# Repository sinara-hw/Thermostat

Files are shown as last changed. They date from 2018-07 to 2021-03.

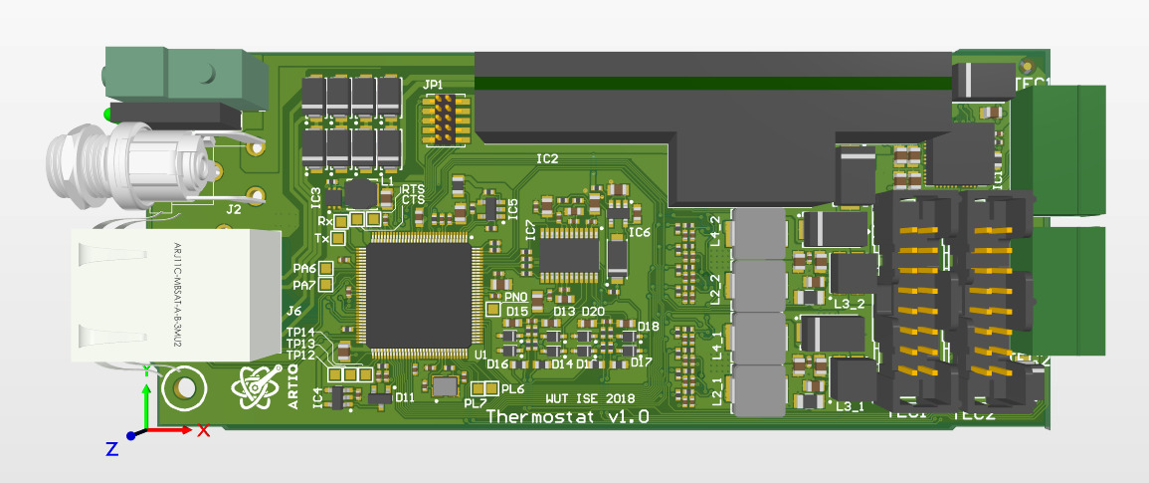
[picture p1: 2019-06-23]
DOC/Thermostat 3U_2.PNG

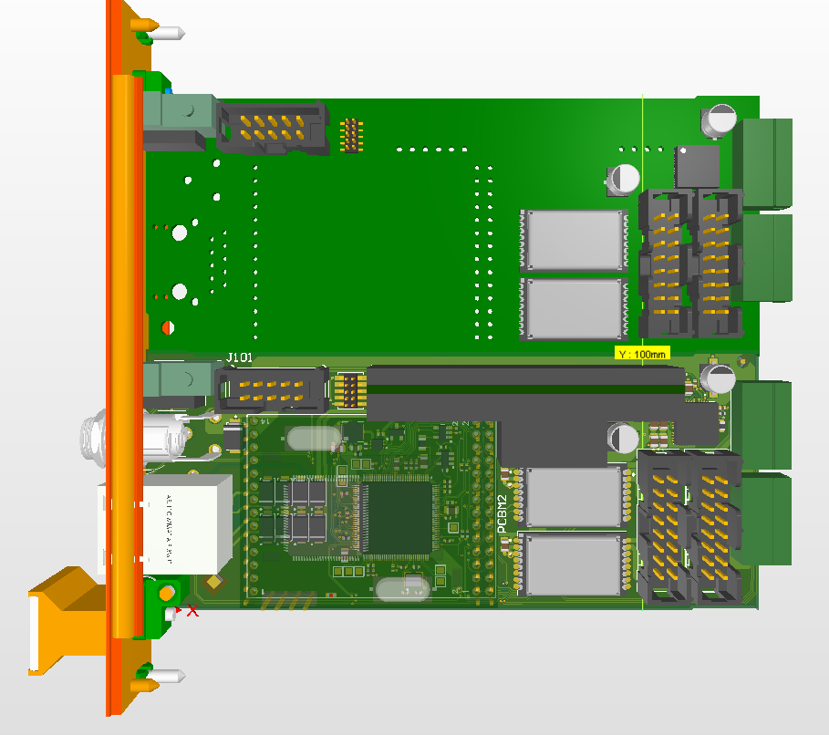
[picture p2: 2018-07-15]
DOC/Thermostat 3U_4.PNG

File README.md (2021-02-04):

# Thermostat

Thermostat is 2-channel temperature controller EEM based on the STM32 ARM processor, AD7172 and MAX1968  capable of driving 8W into a TEC or resistive heater.

## Design Files

Design files (schematics, PCB layouts, BOMs) can be found at [Thermostat/Releases](https://github.com/sinara-hw/Thermostat/releases).

## Wiki

More information can be found on the [wiki](https://github.com/sinara-hw/Thermostat/wiki).

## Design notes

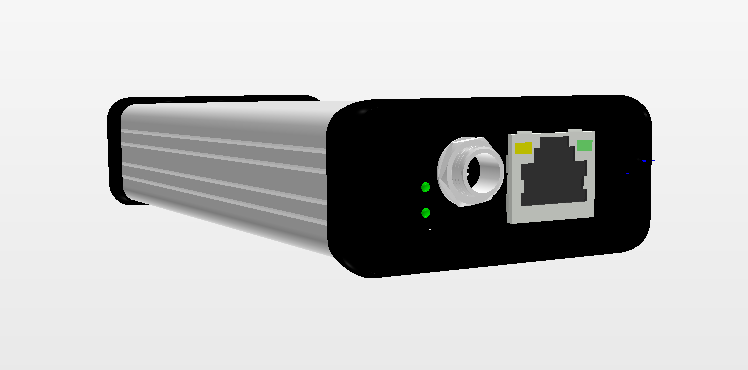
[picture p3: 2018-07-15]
DOC/Thermostat standalone_2.PNG

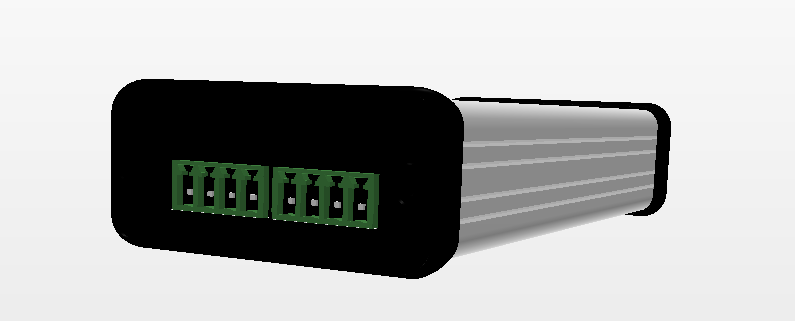
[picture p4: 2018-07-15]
DOC/Thermostat standalone_1.PNG

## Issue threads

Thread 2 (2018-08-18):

project review

gkasprow, 2018-08-18:
@hartytp @jordens I sketched first release.
Please have a look at it.
I also updated wiki with drawings.

jordens, 2018-08-20:
Nice!
1. I'd hook up the ENABLE pins to the uC plus pulldowns and alternatively 0R to GND.
2. You might want to check the output capacitor of the PoE module. They have 470µF there.
3. We need to check that we meet maintain power signature on PoE. That's a couple hundred mW mimimum power consumption IIRC. We should also avoid the acoustic noise the PoE module DS talks about when it runs at low power.
4. Isn't it more efficient to send 5V (instead of 12V) to the other board with the extension channels? The step-down module can handle it and the PoE module as well. You could even use one of those board-to-board edge connectors that you found for Sensor-Box.
5. Can we hook up the LED outputs of the wiznet module to the RJ45 jack LEDs as well?
6. Any chance we can connect pins 15 and 16 (I2C) of the Zotino-TEC connectors to the µC?
9. I'd explicitly pull up RESET of the wiznet module.
7. Congrats to squeezing it on two layers!

hartytp, 2018-08-20:
@gkasprow Great! Travelling atm but will probably be able to look at this in the next few days.

gkasprow, 2018-08-24:
4-channel extension lets you control second module equipped with just TEC controllers from first module with Ethernet, PoE and DC/DC. I'm a bit afraid of exposing 5V to the panel. Someone may plug 12V supply by chance since other EEMs offer such ability.

hartytp, 2018-08-24:
> 4-channel extension lets you control second module equipped with just TEC controllers from first module with Ethernet, PoE and DC/DC.

Okay, makes sense. Have you designed this board yet? Is it worth doing this? IMHO, if people need 4 channels, it's easier to just have two identical thermostat cards with separate ethernet/PoE connections, instead of having to have two separate (non-identical) boards. So, I'd be tempted to scrap this, I don't feel strongly about it.

Also, is there enough power from the PoE module to run 4 TECs safely?

> I'm a bit afraid of exposing 5V to the panel. Someone may plug 12V supply by chance since other EEMs offer such ability.

I meant removing the barrel connector completely and only supporting PoE (I thought this is what we had agreed before). PoE injectors are pretty cheap, so I don't see much need to support both PoE and barrel connectors.

gkasprow, 2018-08-24:
@hartytp It is the same board, but without PoE and Ethernet module.
PoE is rated for 35W

hartytp, 2018-08-24:
sounds good then.

One final request: could you add a comment on the schematic with the p/n (and mating p/n) for those din connectors, please? That way I don't have to load the alltium files to figure it out.

hartytp, 2018-10-09:
Good find. If you use them, let me know how they work out.

gkasprow, 2018-10-09:
@jordens I use them in the lab. I already posted [pics ](https://github.com/sinara-hw/sinara/issues/188#issuecomment-327180612) with them some time ago :) They are really nice.

hartytp, 2018-10-09:
@gkasprow did you ever produce any Thermostat prototypes? I'd like some if they're going :)

gkasprow, 2018-10-09:
Not yet, I'm collecting designs to spare on NRE costs. I will produce it together with Banker extension boards.

hartytp, 2018-10-09:
Good plan. I'm not in a massive hurry for this, but it would be nice to have at some point.

hartytp, 2018-10-09:
Closing this issue since I think the design review is not complete

Closed 2018-10-09.

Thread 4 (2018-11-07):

thermostat v2.0

hartytp, 2018-11-07:
We've had some problems recently with a common commercially available temperature controller, which we've tracked down to inadequate EMI filtering in the temperature controller AFE and use of unscreened cabling in the wiring harness provided by a different vendor (the 10k NTC has a 100uA sense current so is a high-impedance node which is very prone to pickup even at 50Hz).

To solve this, I'd like to swap out these temperature control units for Thermostat, but there are two annoyances:
1. The specified temp co of the Thorlabs chip is quite high and likely to be problematic if we don't temperature stabilise Thermostat, which is a pain
2. We use a resistive heater rather than a TEC for this project. AFAICT there is no software option to make the Thorlabs chips run unipolar (AFAICT the designers didn't consider resistive heaters as an option so didn't bother to implement this in firmware). So, if any transient reduces the heater current below 0 then it will go into thermal run away.

So, I'd like to revive the discussion about replacing the Thorlabs chip with something along the lines of @cjbe's design based on a 24-bit ADC and the Maxim TEC driver IC. As a reminder, the big win from using a 24-bit sigma-delta ADC is that the sample rate is high and the ADC includes very good digital filtering (including extreme rejection of 50/60Hz signals). Combined with a basic CM/DM analog RFI filter, this provides a level of EMI rejection that is essentially impossible to achieve in the analog designs that seem to be used in almost all COTS units. Using @cjbe's prototypes of this design, we were able to achieve stabilities better than 100uK long term without issue.

As I see it, the main challenge here is software. The hardware redesign is very easy and I'd be happy to do that myself using @gkasprow's Altium library. The more involved part is writing decent software: command handler; simple PI(D?) loop; some basic features like thermal runaway detection, current limiting, anti-wind up, etc. I don't have time to do that part. @gkasprow do you have a student who might be interested in doing that? (otherwise, if anyone is potentially interested in funding M-Labs to do this then let us know!)

gkasprow, 2018-11-07:
@hartytp I can add AD7191 to existing design. @cjbe how did you couple the PIC processor with  MAX1968 CTLI input? Using PWM?

gkasprow, 2018-11-07:
We can ask the student to port the PIC code to the TI CPU.

hartytp, 2018-11-07:
> We can ask the student to port the PIC code to the TI CPU.

Which PIC code do you mean?

gkasprow, 2018-11-07:
https://github.com/sinara-hw/Thermostat/issues/5#issuecomment-357445261

cjbe, 2018-11-07:
@gkasprow yes - I generate the CTLI signal from a PWM output and a two-pole reconstruction filter (10k,100n).

hartytp, 2018-11-07:
@gkasprow perfect! I agree: these should be two separate designs rather than trying to fit everything on one board. The Thorlabs version gives us something we can use with minimal effort/risk of hardware bugs, the ADC version should work better in the long run but will need software development and careful hardware characterisation.

gkasprow, 2018-11-07:
@hartytp please have a look
[Thermostat.PDF](https://github.com/sinara-hw/Thermostat/files/2559336/Thermostat.PDF)

hartytp, 2018-11-08:
@gkasprow wow! Thanks for turning that around so fast!

@cjbe any thoughts? Things you'd want to change if you did this design again?

Basically that looks good to go as far as I'm concerned. Small thoughts/comments:
- Cosmetics could be improved but that's non-crucial e.g. would be nice to neaten things up a little, add a power budget, etc. (e.g. I find the fact that the signal flow is R->L on the 3v3->vcc->vref block on the adc makes things a bit hard to follow)
- @cjbe's design is a bit long in the tooth now and there are newer better ADCs around. However, based on his design notes, it seems that the ADC isn't really a limitation here. The only way I can see where the ADC comes close to being a limitation is the +-1ppm/K gain drift. The best ADCs on the market are still only a factor of two better than that, so the overall improvement is relatively small. Probably not worth the hassle of switching ADCs.
- what are the inductors on the TEC driver? Let's use ones that retain their inductance at 1.5A and pick ones that won't radiate like crazy!

jordens, 2018-11-08:
As a humorous side remark: I've heard talks by high profile representatives of well known companies in all seriousness claiming that inductors are what's limiting miniaturization, integration, scaling, and technological progress in laser current and TEC drivers.

hartytp, 2018-11-08:
@gkasprow what capacitors (voltage rating, case size, dielectric) are you using for IC1? That reg needs 1uF for stability, so we need to make sure we don't use a cheapo ceramic which gives far less capacitance when biassed.

gkasprow, 2018-11-08:
You won't find 1uF NPO. I used X7R.

hartytp, 2018-11-08:
Yes, X7R is good for this, but we need to watch the case size and voltage rating or the capacitance can be way lower than expected. Since this is required for stability, I'd probably make it a slightly higher capacitance and use a decent voltage rating and case size.

hartytp, 2018-11-08:
Can you add an annotation that the 5k11 resistors must be 5ppm/K temp co?

(if you upload the altium files I'm happy to do this).

hartytp, 2018-11-08:
@gkasprow let's tie the ADC CLKSEL high to ensure the internal clock is correctly enabled.

hartytp, 2018-11-08:
let's connect the ADC TEMP pin to the microprocessor to allow access to the ADC's on-board temperature sensor.

hartytp, 2018-11-08:
ADC NC should be tied to GND according to the data sheet.

hartytp, 2018-11-08:
We're driving the ADC AVDD and DVDD from the same supply. Usually, I would expect to provide separate supplies for these (e.g. connect the DVDD to P3V3A via an independent 33R resistor with a 1uF||100nF capacitor). @cjbe I guess the reason you chose not to do that in your design is that we keep the digital interface inactive during sampling so we don't need to worry about noise on DVDD. Is that correct, or is it worth isolating?

hartytp, 2018-11-08:
> I used tiny SMD shielded inductors that saturate at 3A.

Since the MAX1968 max output current is +-3A isn't it worth using inductors that saturate at something a bit higher than 3A. We don't want to operate the converter with the inductors close to saturation do we?

hartytp, 2018-11-08:
@gkasprow it's definitely worth adding some schottky diodes to protect the ADC inputs in case the user messes up the wiring harness and connects the TEC outputs to the thermistor input. That would put 5V across the ADC inputs, resulting in an ADC input current beyond the 10mA abs maximum rating. Just use the same diodes on Sampler (to be extra sure, we can split the 100R into 50R->diodes->50R->ADC).

hartytp, 2018-11-08:
not that it really matters, but afaict it's more natural to connect LX2 to tec_n and LX1 to tec_p (i.e. swap the _p and _n around on the tec connectors).

hartytp, 2018-11-08:
Is it worth having a CMC on the TEC outputs to reduce EMI (there is quite a lot of common-mode noise on those outputs)?

hartytp, 2018-11-08:
The TEC driver recommends having a 100uF electrolytic somewhere on the supply to smooth out ripples. Worth adding one?

hartytp, 2018-11-08:
> The TEC driver recommends having a 100uF electrolytic somewhere on the supply to smooth out ripples. Worth adding one?

NB on @cjbe's design this wasn't necessary since we had an external 5V supply with a big output capacitor. However on Thermostat the 5V is sourced from an internal 5V SMPS.

gkasprow, 2018-11-08:
We have to relay on 5V supply itnernal protection then.

hartytp, 2018-11-08:
> We have to relay on 5V supply itnernal protection then.

That can supply 8A, which is more than enough to trash one of the max chips.

I don't think there is any way of getting around this; mis-wiring the connector so that TEC_N, but not TEC_P, is shorted to V+ or GND will always kill this chip.

hartytp, 2018-11-08:
@gkasprow anyway, I don't think this needs to turn into a multi-round review. Do what you think is best based on my feedback, and let me know when you're happy with the design. Once that's done I'll order a few boards from TS to play with.
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
hartytp, 2018-11-13:
> Performance is probably going to be fine for most applications. And if it hinges on me finding a better bridge chip doing the design, then I'll pass ;) And this is probably fine as a first iteration.

Well, it hinges on someone doing the design. I'm short on time right now and the MAX IC will be absolutely fine for all the applications I have in mind, so it won't be me who does all the legwork for this. If you can convince someone else to do the design work required for this then it's fine by me.

What do you think @gkasprow

> In any case, don't you want to wait and debug the parts of the design shared with the Thorlabs version first before signing this one off?

By this point, there isn't much common between the two boards, and I have some temperature control needs coming up for which the Thorlabs chip is a bit marginal. So, unless someone is planning to test the Thorlabs version of Thermostat reasonably soon then I'd prefer to press on to manufacture.

gkasprow, 2018-11-13:
@jordens The MAX works at 1MHz. Even with 10 bit PWM you would need 1GHz clock in CPU. One can do some tricks with 8 bit PWM and noise shaping but IMHO it is not worth the effort.

jordens, 2018-11-13:
The PWM from the CPU to the MAX will also need dithering to get the needed resolution. There is no change from that.

jordens, 2018-11-13:
Even if you were to stay at plain PWM from the CPU, you get even more resolution by adjusting the frequency. The continued fraction algorithm to do that will fit just fine into the ~10ms sample rate. I assume that's what @cjbe was already doing.

hartytp, 2018-11-13:
> Even if you were to stay at plain PWM from the CPU, you get even more resolution by adjusting the frequency. The continued fraction algorithm to do that will fit just fine into the ~10ms sample rate. I assume that's what @cjbe was already doing.

@cjbe

gkasprow, 2018-11-13:
I"d like to treat the version with MAX chip as a first iteration.
 Doing own HW bridge with cycle per cycle current sensing needs quite sophisticated mechanisms inside of the CPU.
Once I did laboratory grade BLDC motor driver using brand new special AVR chip dedicated for that tasks with special high resolution PWMs with HW dithering, synchronous ADCs, HW protections, etc but it took  enormous amount of time due to bugs in the silicon. Finally I had to build required functions writing critical parts in assembly. And I burned a lot of MOSFETs during testing because HW protection functions (programmed using fuses) did not work as expected causing spectacular failures by switching top and bottom switch at the time :)
Every design can be made better, but if MAX chip does the job and simplifies R&D, let's use it. If we discover that it does not meet our expectations, we will switch to something else.

hartytp, 2018-11-14:
@gkasprow It sounds like the plan is to keep the MAX IC for Thermostat v2.0. If we decide it's not good enough, we can replace it in v3.0. Thermostat v2.0 will give us a high-performance board that we can develop most of the required firmware on.

Please could you update following @jordens comments (copied below) and then upload a release and close this issue?

- [ ] also connect I2C on the second TEC to the CPU. I2C2 or I2C3 (when moving STAT) seem doable on quick glance.
- [ ] Please expose the UART not on individual pads but on a pin header.

gkasprow, 2018-11-17:
done for both designs.

hartytp, 2018-11-17:
Thanks!

Okay, let's close this. We'll keep the new TEC driver design in mind for v3.0

Closed 2018-11-17.

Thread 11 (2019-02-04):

replace PWM with a DAC

hartytp, 2019-02-04:
I'd like to replace the PWM for the TEC controller with 16-bit I2C DACs with internal references like AD5693R to the next revision. Seems easier than fighting to squeeze the last bits out of PWM and won't make a significant impact on the board ownership. We can always re-visit PWM if we move to a custom TEC driver in a future revision.

Any objections?

gkasprow, 2019-02-04:
@hartytp sorry, I have higher priorities. I'm just moving all Sayma/Metlino designs to AD19. Mentor didn't agree to renew the Xpedition license for WUT. Once Siemens bought Mentor, the rules changed.
We still have a commercial license but it expires in March. After that, we won't have any. I got to know about it a few days ago... I will write another post about it.

hartytp, 2019-02-04:
Ack no problem. Can you post me the boards then and I’ll make the changes.

First, any objection to adding DACs (@jordens).

hartytp, 2019-02-15:
@gkasprow to ensure that Thermostat works well for high dynamic range applications, let's go for an 18-bit DAC.

AD5680 looks to be a good choice. NB INL is really quite large (12-bit accurate, but 18-bit montonic), but that's not an issue for this kind of application. It does require an external reference. The reference doesn't need to have a low temp co or amazing low frequency noise since it's mainly intended to be used closed loop. So, pick any suitable buffered ref. A common reference for the two DACs will be fine.

hartytp, 2019-02-16:
Thinking about this a bit more, it's probably best to use the TEC driver's REF output for the DAC reference.
- the TEC has a low-accuracy, somewhat drifty reference. This sets the control voltage that gives 0 TEC current. For systems that use low TEC/heater currents, getting this right is quite important.
- our original plan was to use an ADC to calibrate the TEC driver reference using the reference output pin. This relies on having quite accurate ADCs in the microprocessor and uses a bit more software work.
- let's just use a cheap low-speed OpAmp in a small package like 5-pin SOT as a 2x buffer to cover the TEC reference to a DAC reference. That way most systematics common-mode out and we don't need to bother with software calibration or external references.
- If we do that, it makes sense to use a DAC with decent offsets/INL, so I'll pick a different PN

jordens, 2019-02-16:
Are you sure the zero offset is critical? It only determines the proper reset value of the integrator and it is only as critical as accurate knowledge of the ambient temperature.

hartytp, 2019-02-21:
> It only determines the proper reset value of the integrator and it is only as critical as accurate knowledge of the ambient temperature.

For TEC/heater currents that are larger than the offset, that's true. However, if the TEC/heater current gets smaller than the offset then the sign of the feedback gain changes, which can get a bit nasty (Thermostat thinks it's heating when it's actually cooling).

Anyway, this isn't an issue for any of the systems I have in mind, so I haven't put much thought into it.

> Thinking about this a bit more, it's probably best to use the TEC driver's REF output for the DAC reference.

Actually, I'm not sure this is worth the effort. To get decent accuracy, we'd need a resistor ladder/PGA and it's not at all clear that the gain would be worth it.

Once we have a PN for the microprocessor, we should check the accuracy of the ADCs and decide whether it's worth doing a power-on calibration of the TEC driver reference + DAC offset or not. This is a pretty low priority for me though.

gkasprow, 2019-02-21:
we can assume same CPU PN as in the Stabilizer.

hartytp, 2019-02-21:
Okay, those ADCs look pretty good. I suspect that if we measure the DAC offset with the same ADC as the TEC driver offset, the ADC offsets will common-mode out, so we should get a nice accurate measurement of the zero-point current without any clever tricks.

We could derive the DAC reference from the TEC controller to take out drifts/noise in the TEC controller reference after calibration, but I don't think it's worth the effort.

jordens, 2019-02-21:
> For TEC/heater currents that are larger than the offset, that's true. However, if the TEC/heater current gets smaller than the offset then the sign of the feedback gain changes, which can get a bit nasty (Thermostat thinks it's heating when it's actually cooling).

I don't think so. This sounds like the typical wrong PID design (gain after integration instead of the other way around).

hartytp, 2019-02-21:
Yes, you're right, it's not an issue. Anyway, it's not relevant for the use cases I have in mind, so wasn't putting enough thought into it. Glad you're paying more attention!

gkasprow, 2019-06-21:
The CPU has 2 DAC output channels. Can we use them for something instead of PWM?

gkasprow, 2019-06-21:
@hartytp What is the conclusion for driving the DAC reference? We will measure the TEC ref with CPU ADC?
I already connected it in such manned.

hartytp, 2019-06-21:
Yes, let’s connect the tec driver ref to an ADC. Drive the dac ref from a buffered voltage reference.

Closed 2019-06-23.

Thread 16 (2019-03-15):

enclosure mechanics

jordens, 2019-03-15:
* The tantalum cap in the corners next to the green terminals and the IDC connectors are too close to the enclosure
* There are PCB traces at the edge that risk being scratched and shorted by the enclosure when inserting
* The pins from the RJ45 and the green terminals touch the enclosure.
* Inserting it in the second slot from the bottom doesn't work because of the RJ45 connector.

I'd make sure that there is enough clearance to the side slots (tantalum, IDC, other parts parts and traces) and that the pins are cut.

gkasprow, 2019-06-23:
we are switching to 4 layer PCB anyway so this will solve some of the issues.
THT pins need trimming before placing in the enclosure.

hartytp, 2019-07-15:
I also had issues with the PoE module colliding with the side on one board. Maybe it was soldered on at a bit on an angle, but I had to bend it in to prevent some thicker components from colliding with the enclosure.

gkasprow, 2019-10-26:
All issues fixed. At least on the 3D model.

Closed 2019-10-26.

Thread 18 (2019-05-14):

add GPIO header?

sbourdeauducq, 2019-05-14:
What about adding a GPIO header connected to the otherwise unused pins of the STM32?

The immediate application I have for it is connecting a current source driving a laser diode, to study its behavior under different temperature and current conditions. With that GPIO header, the diode driver could be a simple stripboard add-on.

gkasprow, 2019-05-14:
What about using same connector as for Stabilizer , routed to same CPU
pins, so one can reuse same mezzanines?

hartytp, 2019-05-14:
The Stabilizer connector is probably too big for Thermostat. I'd prefer not to increase the board area too much for a niche feature.

jordens, 2019-05-14:
I would prototype a current driver on Stabilizer or any of the other µC (e.g. Nucleo) boards and use Thermostat separately.
If there is space for a connector without disturbing the layout, introducing clearance problems, or changing the board size I'm ok with adding one.

sbourdeauducq, 2019-05-14:
> I'd prefer not to increase the board area too much for a niche feature.

Niche?
I thought one of the main applications of the thermostat was to stabilize the temperature of laser diodes, and those almost always needed programmable current sources.

gkasprow, 2019-06-23:
what signals would you want on such header?
I have some board are and can place 10 pin 2.54mm header.

gkasprow, 2019-06-23:
I can route 2 ADC, 2 DAC and some GPIO

sbourdeauducq, 2019-06-23:
Okay, sounds good!

Closed 2019-06-23.

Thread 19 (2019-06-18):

AD590 temperature sensor support?

sbourdeauducq, 2019-06-18:
The AD590 seems to be a popular option in several commercial or academic ECDL designs, and it might be interesting to support it.

gkasprow, 2019-06-19:
it is current output sensor, with 1uA/K conversion ratio.  It gives 300uA at room temperature and 220uA at -55degC.  The only issue is the power supply. It needs a minimum of 4V. We would need to hook it to 5V rail and measure the voltage on a resistor connected to GND. If we use existing 5k11 resistor, we would get
1.55 V at room temperature so 5V supply would be not enough. So the resistor must be lowered to roughly 3k to maintain the best SNR. The negative terminal of the ADC would need to be shorted to GND.
So, there is a way to do it but it would require additional LDO that stabilizes 5V to let's say 4.8V, some jumper that chooses the lower value of the resistor and yet another one that connects LDO output to positive ADC pin.

hartytp, 2019-06-19:
The current thermostat design is optimized for ratiometric measurements of resistances ~10k. In particular, this allows us to avoid using a high-spec reference, since the reference voltage/noise common-modes out.

The AD590 is quite different since we'd need to measure an absolute current/voltage across a sense resistor. 1mK/300K=3ppm. So the noise/drift on the reference has to be very low to achieve decent stability. Moreover, to get 0.5C accuracy on 300C you need the reference to be good to 0.1%, which the current implementation isn't.

So to make this work we'd need to overhaul the ADC supply/reference.

hartytp, 2019-06-19:
Assuming we used a 1V sense resistor, the 1mK=1nA*1kOhm=1uV. So, we'd need to be very careful to make a proper differential/kelvin-connection measurement across the sense resistor. The current circuit topology doesn't allow that. I suspect that just grounding one ADC input and making a single-ended measurement of the sense resistor voltage won't give very good results.

hartytp, 2019-06-19:
In other words, this is something we can do with a handful of jumpers (maybe FETs, but that would need some thought) and an overhaul of the ADC reference/supply, but it's not a trivial change.

I wouldn't support going down this rout unless someone wants to take ownership of it and provide a sketch of what conenctions we'd need, along with a noise/stability analysis and a specification of what they're trying to achieve. If no one has time to do that right now then let's leave it to a future design revision (or maybe a design variant).

jordens, 2019-06-19:
Thermistors are also about 20 times more sensitive than a PTAT. That translates to controller performance accordingly.

gkasprow, 2019-06-23:
nothing to do here, closing.
I don't have space on PCB to add jumpers.

hartytp, 2019-06-24:
I think the best thing is to make a separate PCB for the AD590 if people need that. The front-end circuit required for the AD590 is sufficiently different to RTDs to make supporting both tricky without significant space/complexity increases.

Closed 2019-06-23.

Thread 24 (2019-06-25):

ic1 sw pins connection missing

hartytp, 2019-06-25:
why aren't pins 10 and 48 tied together?

hartytp, 2019-06-25:
@gkasprow answering my own question, I guess the reason is that there are two banks of SW pins on opposite sides of the IC and you don't want to route them together.

Also, I haven't checked the compensation for this reg, but assume you're happy with it?

gkasprow, 2019-06-26:
I took the values from the datasheet.

hartytp, 2019-06-26:
@gkasprow looking at the example layout (fig 6-1) the two sets of switch pins should be tied together with a thick trace.

hartytp, 2019-06-26:
@gkasprow I didn't see much guidance in the data sheet on the choice of Cinj and Cff. It looks a bit like they have to be chosen empirically (depends a lot on the ESR of the capacitors used). Are you happy with the values there? Did you check the stability/noise of this regulator?

gkasprow, 2019-08-18:
I took them from the [reference design](https://www.arrow.com/en/reference-designs/mic45116-1ymp-ev-evaluation-board-for-the-mic45116-1-20v6a-dc-to-dc-power-module/98683d59703926eaa41bfb0839684ba1)

gkasprow, 2019-10-26:
I think I have to look at it once again and verify its stability with a step response test.
The sudden death of the 3V3 converter made me suspicious. I'm using this configuration in a few other designs and nobody complained so far but since a lot depends on load, who knows...

gkasprow, 2019-10-26:
I can also do it with V2.0 since I don't have any thermostat in my hands.

hartytp, 2019-10-27:
Happy to send you one if it would help?

gkasprow, 2019-10-27:
I have other design with an identical converter so can use it for testing.
I do a very simple test:
 Connect a scope and a pushbutton with a 2R/5W resistor in series.
One probe goes to the switch, another to the power rail. Then trigger on falling and rising edge and observe the response. It cannot oscillate. If it does, there are stability issues.

hartytp, 2019-10-27:
Good idea. FWIW I think we’re running at a quite light load, not sure how that impacts stability

hartytp, 2019-11-30:
@gkasprow are you happy the layout for this ic follows the reference design?

gkasprow, 2019-11-30:
yes.

Closed 2019-11-30.

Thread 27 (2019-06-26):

DAC reference

hartytp, 2019-06-26:
@gkasprow shouldn't we use a 3V reference for the DAC to match it to the TEC driver? Currently we're throwing away nearly an entire bit of resolution by using the wrong reference.

gkasprow, 2019-06-26:
True. We can also add resistive divider but the reference is probably cheaper.

hartytp, 2019-06-26:
Nb the dac still needs a decent 5V rail as it doesn’t support 3V vcv

hartytp, 2019-06-26:
> True. We can also add resistive divider but the reference is probably cheaper.

Actually, we can probably get away with a divider made from 0.1% resistors. After all, the DAC offset is 10mV, which is 0.3%, so a small error on the reference won't harm us.

hartytp, 2019-06-26:
And, DAC gain accuracy is only 1.5% so no point having an ultra-precise reference.

The main worry I'd have would be the higher reference impedance degrading the DNL. @gkasprow am I right in thinking that for this kind of resistor string DAC, that shouldn't be a problem since the ref current is constant? Or do we need a proper buffered reference here?

gkasprow, 2019-07-12:
@hartytp AD5680 has already buffered output. So we can add resistors.

hartytp, 2019-07-12:
Won’t it be an issue that the ref impedance at the ac will be high due to the resistors? Doesn’t the dac need a low impedance red?

gkasprow, 2019-07-13:
Oh, I was thinking about adding voltage divider at the DAC output to match the range.

gkasprow, 2019-07-13:
we can also use the ADC 3.3V supply as a reference.

hartytp, 2019-07-13:
Aah ok. So long as the tec and cpu ADC inputs are high z, a divider on the dac output sounds like the best option

gkasprow, 2019-07-13:
MAX1968 has 1MOhm input resistance. We don't really care about DC accuracy. So resistive divider in order of 1k should be fine.

hartytp, 2019-07-13:
Sounds good

Closed 2019-08-18.

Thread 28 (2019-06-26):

mesaure DAC output on microprocessor

hartytp, 2019-06-26:
@sbourdeauducq should we wire the DAC output to a microprocessor ADC input? The DAC only has 12-bit accuracy (10mV offset), which is comparable to the TEC driver. No point calibrating the TEC if we don't calibrate the DAC as well.

hartytp, 2019-06-26:
This also means we're not sensitive to offsets in the microprocessor ADC since they common-mode out on the two measurements (we're effectively finding the DAC word that makes the DAC output equal to the TEC ref value).

gkasprow, 2019-06-26:
>  The DAC only has 12-bit accuracy (10mV offset)

Do you mean the CPU ADC?

hartytp, 2019-06-26:
No the 18 bit DAC is only 12 bit precise as it’s designed for in loop applications like this. 18 bit accurate dacs cost $$$ this one is cheap. Stability and noise are good so it’s fine for our application

hartytp, 2019-06-26:
CPU ADC offsets don’t matter so long as we measure the dac outputs and tec ref on the same ADC

gkasprow, 2019-06-26:
I added another RC to isolate the DAC from the CPU ADC sampling current pulses

hartytp, 2019-06-26:
When did you add that?

gkasprow, 2019-06-26:
a few seconds ago.
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

hartytp, 2019-06-26:
Did it make any difference?

hartytp, 2019-06-26:
In the first instance, let's try to focus on allowing you to reproduce my results on an unmodified board. See if you can get +10V on channel 0 and -10V on channel 1 by flashing according to Robert's instructions. If not, I'll have another look at the FW I sent you in the morning.

gkasprow, 2019-06-26:
It's thermostat issue, not stabilizer :D

hartytp, 2019-06-26:
:) sorry. Doing too many things at once

hartytp, 2019-06-26:
Looks good

jordens, 2019-06-30:
When using the DAC and PWM Vref calibration values that you would obtain from this, I'd be very careful what to do with them. Initial one-time offset calibration, monitoring and correcting the limit PWMs later on are fine. But I don't think repeated feedback of those values onto the Iset DAC output are a good idea.

hartytp, 2019-06-30:
@jordens yes I’d go for a power on cal and leave it there.

Closed 2019-08-18.

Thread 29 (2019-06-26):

schematic review

hartytp, 2019-06-26:
I've checked the supplies and analog parts and am happy. @sbourdeauducq / @jordens would you mind checking that you're happy with the digital side of things?

gkasprow, 2019-06-26:
I posted also CubeMX config files, so one can with one click generate all init software for specified pin assignment and peripherals.

jordens, 2019-06-30:
I would recommend testing and characterizing the analog parts sufficiently before doing the redesign.

hartytp, 2019-06-30:
@gkasprow do you have a thermostat set up with firmware already? Do you think you could have a quick look at the temperature stability this week? Just connect a low temp-co 10k resistor in place of a RTD and log the temperature for a few hours.

gkasprow, 2019-06-30:
I don't have any Thermostat at the moment.

hartytp, 2019-06-30:
I have a spare one I’m happy to send you (btw did TS send you a stabilizer current sense AFE?)

gkasprow, 2019-06-30:
I gave one to Creotech, can take it back if they don't use it. I didn't get stabilizer AFE from TS. Note that at the end of next week I'm leaving for the holidays. I will stay for one month in the US.

hartytp, 2019-06-30:
> I gave one to Creotech, can take it back if they don't use it.

Okay, I'm happy to overnight you one tomorrow if it would help.

> Note that at the end of next week I'm leaving for the holidays. I will stay for one month in the US.

I think it's important that we try to get the boards off before you leave. I need to get hw produced before too long so that M-Labs can write the new firmware. Let's do as much testing as we can (I will try to do some as well), but still aim to get production files ready by the end of the week. (@jordens / @sbourdeauducq can you try to finish your design reviews in the next few days?)

> I didn't get stabilizer AFE from TS.

Odd, I asked them to send you one. They must have forgotten. I can ship at the same time as Thermostat or bring one to NACTI if that helps?

gkasprow, 2019-06-30:
You can bring to NACTI.

hartytp, 2019-06-30:
Okay. I’ll do what testing I can this week (anything anyone else can do gratefully received) but let’s aim to get the next design rev ready for production before @gkasprows holiday

hartytp, 2019-07-03:
@jordens @sbourdeauducq other than the thermal management have you completed your design review?

jordens, 2019-07-03:
I have reviewed everything in my area of expertise except the µC pin assignment. With the pending changes, that'll change quite a bit. Someone should take a good long look at that the choice of peripherals, timer channels, w.r.t. pins, internal buses, dma architecture, peripheral capabilities etc. I won't have much time to do that in the next weeks.
And I would still recommend that someone does a decent amount of characterization and testing of the current device. Both ADC and TEC driver.

gkasprow, 2019-07-03:
For this purpose, I use STM32CubeMX which does most of the job you mentioned.

jordens, 2019-07-03:
Sure. Some. It didn't cover the peripheral specific properties for stabilizer for example.

Closed 2019-10-26.

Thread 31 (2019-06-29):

AG5300 bypass/EMI filters (was: ripple capacitor)

jordens, 2019-06-29:
Should be 470 uF, is 460.
Imo going to 3*220 would be nice.

Also and maybe more importantly:
Is there some way to mitigate the ground ripple?
Since it's an actual isolated transformer I would not have expected ground loops that bad.

gkasprow, 2019-06-29:
it does not make any difference because tolerance of electrolytic caps is usually 20% or worse.
A higher value may cause PSE tripping.

jordens, 2019-06-30:
What about adding the bypass caps (4.7nF 2000V) around the module and the choke for emi filtering as in the datasheet (fig13)?

gkasprow, 2019-06-30:
Good idea. The same with Stabilizer.

jordens, 2019-06-30:
Although the RJ45 connector seems to contain some caps already.

gkasprow, 2019-06-30:
Yes, but they are in series with 75Ohm.
The CMC and cap mentioned in the datasheet are used to make a bypass for PoE module Flyback converter.
The converter injects noise between primary and secondary side. Cap placed between them shorts the interferences and CMC is used to break the ground loop.

jordens, 2019-06-30:
But interestingly there are no caps on the non-data pairs.

gkasprow, 2019-06-30:
The RC network inside of the RJ connector serves a different purpose. It is so called "Bob Smith" termination. However, there are [doubts](https://www.eetimes.com/document.asp?doc_id=1277940#) if the values are correct.

gkasprow, 2019-06-30:
The conclusion is that we would need CMC to keep Bob Smith termination working. This affects EMI performance.

hartytp, 2019-06-30:
> Since it's an actual isolated transformer I would not have expected ground loops that bad.

To be clear, are you referring to https://github.com/sinara-hw/Stabilizer/issues/17#issuecomment-506049460

hartytp, 2019-06-30:
> The CMC and cap mentioned in the datasheet are used to make a bypass for PoE module Flyback converter.

@gkasprow which CMC? I only see ferrets there

hartytp, 2019-06-30:
@gkasprow can you sketch out your recommended circuit for this?

hartytp, 2019-06-30:
When I was looking at noise on Stabilizer, I didn't see a difference between powering from PoE or an external power supply. However, I did notice that when I turned the the PoE switch on with no cables connected (other than the power supply) I suddenly saw a lot of switching spikes on my scope. Maybe it's an issue with the particular switch I'm using, but maybe we should be prepared for some grounding/noise issues with PoE...

jordens, 2019-06-30:
Yes. It looks very different depending on the switch, the PoE mode.

gkasprow, 2019-07-12:
added CMS and caps.

hartytp, 2019-07-12:
Nice. Can I see the circuit you added? Did you use cmcs or inductors (as in the data sheet?)

gkasprow, 2019-07-12:
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

hartytp, 2019-07-12:
Wouldn’t inductors/fbs be better? We want to block both the cm and the dm signal, but the choke only gets the cm.

hartytp, 2019-07-12:
Also do c3 and c12 need to be he caps? And should we use 4.7nF input to output caps instead as in the data sheet?

gkasprow, 2019-07-13:
True, we can add inductors, but CMCs are much smaller. The main issue is common-mode noise caused by the DC/DC converter. The inductors in the datasheet of the PoE module are ferrite beads that have Z close to zero for SMPS frequency. C3 and C12 need to be high voltage caps to be compatible with Ethernet isolation barrier. Their role is to make a bypass for PoE noise source.

hartytp, 2019-07-13:
Okay so long as you’re not worried about dm noise currents radiating and causing emi issues that sounds good.

Closed 2019-07-12.

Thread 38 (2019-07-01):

evaluate thermal design and cooling requirements

jordens, 2019-07-01:
From a rough calculation where the three switchers (PoE, the 12V-5V, and the MAX) are each about/at most 90% efficient, we'll be loosing more than 30% in the device (plus µC, MAC, ADC, DACs, LDO, references). At `3A*4.3V*2` that's 26W to the Peltiers and we will be burning another 9W on top on this tiny board. That number is typically reached each time during turn on for a significant duration. (I have seen it use about 17W from PoE+ when driving a single channel. That wasn't even max power.)
This means:

* In unconstrained applications we'll max out the PoE allowance (25.5W available at PD since you need to account for cable losses). This will require careful and active management in software. It's not a killer. But it means that it will be impossible to get full power out of both peltiers at the same time for a significant duration. If it's not managed in software this will be annoying and confusing at the very least.
* Since there is no way for the software to distinguish PoE (where AT_DET is deasserted) from external 12V (where it is deasserted as well) using the 12V external will mean running at 13W max from the barrel connector. If this is undesired we need a way to distinguish the power sources.
* For PoE power at full output we'd burn more than 8W on the device. For external 12 V at full beans it's more than 5.5W. This will likely overheat if continuous. One way to tackle this may be to try to get some conductive cooling working to the Hammond enclosure: add tight coupling between the PCB layers, add exposed copper/gold strips on the outside where the PCB slots into the enclosure and design two wedges that are inserted from rear and front on top of the PCB between the enclosure and the exposed strip to make thermal contact. Admittedly that's a hack and tricky. If that doesn't work, we need to look at something else. E.g. actively limit the Peltier voltage depending on internal (ADC, µC) temperatures.

hartytp, 2019-07-01:
@jordens all good points. Thanks for the detailed work on this.

> Since there is no way for the software to distinguish PoE (where AT_DET is deasserted) from external 12V (where it is deasserted as well) using the 12V external will mean running at 13W max from the barrel connector

The barrel connectors have a connector inserted signal don't they? We should connect it to the uC.

> One way to tackle this may be to try to get some conductive cooling working to the Hammond enclosure: add tight coupling between the PCB layers, add exposed copper/gold strips on the outside where the PCB slots into the enclosure and design two wedges that are inserted from rear and front on top of the PCB between the enclosure and the exposed strip to make thermal contact. Admittedly that's a hack and tricky. If that doesn't work, we need to look at something else. E.g. actively limit the Peltier voltage depending on internal (ADC, µC) temperatures.

Yes. This shouldn't be an issue if Thermostat is used in a rack with some forced air cooling, but will be an issue in those small enclosures. @gkasprow what's your plan here?

Is it worth putting a thermometer IC that can shutdown the 5V rail if the temperature near the TEC driver exceeded a safe limit? Or do we want to do that in SW only?

jordens, 2019-07-01:
Doesn't matter if it's an issue only for some configurations. If it's an issue for one of the target configuration it should to be addressed. For the 3U version you will also need quite some flow to pull away 10 W from that small surface. Thermostat has about 3 times the power (loss) density than Urukul/Mirny. And conducted heat transfer from the PoE module in the enclosure will likely be pretty bad.
The PoE module will shut down at 70C which I think we will reach rather quickly. For safety (in the case of PoE only) that seems good to me. I would recommend optimized cooling and a proper software solution for the remaining factors.

hartytp, 2019-07-01:
> Doesn't matter if it's an issue only for some configurations. If it's an issue for one of the target configuration it should to be addressed.
> ...
> I would recommend optimized cooling and a proper software solution for the remaining factors.

Agreed.

I'd be interested to hear @gkasprow's feedback on our options for improving the thermal design.

gkasprow, 2019-07-01:
I would add LM75 that would shut down the power after exceeding 80 degrees.
It's not a big problem to add a circuit that makes CPU aware of the power source.
When I designed the Thermostat, the assumption was that we would work with much lower TEC power. Even 15W PoE seems to be sufficient, I used 30W one to have some margin. The idea was to keep the power output of the Thorlabs module at +/- 1.5A level.

gkasprow, 2019-07-01:
To improve heat transfer, we can do one of the two things:
- reserve some exposed copper area on the PCB where flexible copper-silicone pads can be glued which transfer the heat to the enclosure. We cannot really rely on edge heat transfer, we would need to use complicated wedge-locks.
- machine dedicated aluminum pads that would be slid between PCB and the enclosure and screwed from the bottom side to keep low thermal resistance.

hartytp, 2019-07-01:
The other thing that might be possible would be a right-angled aluminium bracket that mounts to the edge of the PCB and screws to a hole on the side of the enclosure to transfer heat. Or something like that.

hartytp, 2019-07-01:
Maybe better to make the front panel out of metal try to ensure a good thermal contact between it and the PCB. Rely on the PCB copper to spread heat

jordens, 2019-07-01:
Imo active temperature measurement and power and temperature limiting in the CPU is good. Just needs to be done properly.
Together with best effort cooling (conductive and sinking) it's just fine.

gkasprow, 2019-07-02:
That's why I like these LM75 chips. They are chip and provide thermal shutdown without any programming. So, even when somebody forgets to initialize thermal management, the board will still survive.

jordens, 2019-07-02:
In this case they wouldn't matter. The Poe module will shut off 10K earlier unless you configure the lm75.

gkasprow, 2019-07-03:
True, but this would work with DC power.

hartytp, 2019-07-03:
Imho it’s worth having a lm75 or similar to shut off the 5V and protect the circuit in case of damage (the PoE module is not in good thermal contact with the PCB so could be quite a bit cooler than the TEC driver).

Even if we dnp/remove if once the fw is working ime it’s good to have hardware fail safes during debugging/development

hartytp, 2019-07-03:
@gkasprow how hard/expensive/practical  would it be to add a heat sink + fan combo to thermostat and add a grill in the enclosure?

hartytp, 2019-07-03:
It’s nice to have the option of running close to max power for a prolonged period if we can, rather than just hitting a second/hw thermal shutdown.
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
hartytp, 2019-10-27:
I think that’s right: either software limit the tec power to something low or design a different enclosure with forced air cooling (use a eurocard rack I guess)

hartytp, 2019-11-18:
Trying to summarise the options that have been presented here for improving the thermal management...

NB We don't necessarily need to implement all of these, they are just suggestions.

**1. conductive cooling** (heat sinking to the case)

- now we're using a 4-layer PCB we have more ground copper, which should significantly improve heat conduction through the board
- make sure to add plenty of thermal vias near components that generate heat
- have some exposed copper around the edge of the pcb
- use some thermally conductive filler material to ensure a good contact between the board and the case (see https://github.com/sinara-hw/Thermostat/issues/59#issuecomment-553641546) . @gkasprow should we add this to the BOM with an explanatory note for the next design revision?
- the (electrically insulating) fillter material can potentially cover the whole top-side of the PCB to improve conduction
- NB the PoE module does get pretty hot (see here https://github.com/sinara-hw/Thermostat/issues/59#issuecomment-553382294 we also have other photos that give a direct measurement of the PoE module that we can post) and will not be directly helped by this

**2. I2C Thermometer**

- add an LM75 I2C thermometer. I know there is one in the ADC, but using that costs us loop BW, so it's nice to at least have the option of using a separate one for slow temperature measurements.
- hook up the over temperature alarm to the microprocessor on a pin that can generate an interrupt.
- Also hook this up to the TEC driver shutdown pins, so that it is ORed with the microprocessor outputs (i.e. either the microprocessor or the LM75 can shut the TEC driver down).
- also hook up to an over temp LED on the FP (again, maybe OR that with a microprocessor output?)
- NB the TEC controller, PoE module and 5V SMPS all have thermal limiting, so the LM75 thermal shutdown should not be required to prevent damage

**3. software**

For a future design revision we should consider adding thermal management to the software. e.g. limiting the max power through both TECs to keep the board acceptably cool and avoid overloading the PoE module (we should also look at the AT-DET for this). Right now, one can turn both TEC drivers to max with a 1Ohm load, resulting in the PoE switch cutting the supply off.

**4. add heat sinks**

e.g. add a pad for a low-profile SMT heat sink under the ADC. This will be useful e.g. then thermostat is used in a case with forced-air cooling

**5. fan header**

Do we want to add a header for a fan? This might be useful in stand alone applications in vented boxes.

gkasprow, 2019-11-21:
I added a simple R + Diode solution to disable both TECs. FP LED is also connected. CPU is connected to the LM75 alarm output.
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

I added the pad under ADC with vias and silkscreen removed
I'm not sure if exposed copper on board edges would improve heat transfer. The contact area is very low. Such exposed copper would short with enclosure and create new ground loops.
I managed to place standard fan connector but will make it DNP by default
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

jordens, 2019-11-21:
Sounds good.

hartytp, 2019-11-22:
will that fan header collide with the Box/rack mounting rails?

hartytp, 2019-11-22:
What's the plan for the thermally conducting pads to transfer heat to the enclosure?

hartytp, 2019-11-22:
Ok, it seems like we're nearly there. @gkasprow do you think it's feasible to aim to send Thermostat v2.0 to production on Monday?

gkasprow, 2019-11-29:
the header fits, at least according to the 3D model.
I will try the 3M conducting sheets I have in the lab.

hartytp, 2019-11-29:
Cool.

> What's the plan for the thermally conducting pads to transfer heat to the enclosure?

?

hartytp, 2019-11-29:
> I will try the 3M conducting sheets I have in the lab.

Okay, sorry, I missed that. Will you do this before sending to production?

gkasprow, 2019-11-29:
I don't have any thermostat to test them. I can glue such sheet to v2 and see how it performs.

hartytp, 2019-11-29:
Let’s do that.

In practice I think we’ve done all we can to improve this design so I’m happy to finalise the pcb here

gkasprow, 2019-11-29:
fan supplies are routed far away from the ADC and they do not form ground loop.

hartytp, 2019-11-29:
@gkasprow i think this is all done so you can close unless you think I missed something

gkasprow, 2019-11-29:
I drafted new release
https://github.com/sinara-hw/Thermostat/releases/tag/v2.0rc4

Closed 2019-11-29.

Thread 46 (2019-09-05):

v1.0 analog tests

hartytp, 2019-09-05:
Tests I propose to do:
- [ ] TEC driver at 0 current (no load) use a 10k precision resistor instead of thermistor and measure noise/stability . Put the resistor as close to thermostat as possible to limit room for pickup
- [ ] same as previous but put the resistor at the end of a few m of screened twisted pair cable
- [ ] same as previous, but with the TEC set to a few different currents between +- full-scale (using a resistor as a load)

I think that will be enough to verify the basic functionality before finalizing the v2.0 design, but let me know if anyone thinks there is anything else we should do.

jordens, 2019-09-05:
When doing the last one, do it with PoE, both TEC drivers at full current and use the opportunity to take a couple thermal camera photos. That would yield a lot of info on #38 .

hartytp, 2019-09-05:
> When doing the last one, do it with PoE, both TEC drivers at full current

How much power can the PoE supply in v1.0?

Otherwise, sure, if I can track down a thermal camera I'll do that.

jordens, 2019-09-05:
Full beans. 25.5W to the device. But even with external 12V it would be useful if you don't have 803.2at.

hartytp, 2019-09-05:
Okay, I'm not up to speed on this, but I though that required the AT detect line doesn't it? Or does that just tell the CPU what power is available?

Okay, I'll see how much juice my PoE switch has and run this as hard as possible from both sources.

jordens, 2019-09-05:
The AT line is just for letting the CPU know that it is allowed to draw that much.

hartytp, 2019-09-11:
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

@jordens doesn't this imply that the firmware usually needs to do something to enable >15W of power from the switch?

jordens, 2019-09-11:
Where does it say that?
Classification is negotiated between PSE and PD (the module) and then signaled to the CPU via AT. There is nothing the CPU can do.

hartytp, 2019-09-11:
In the docs I pasted above, the module states that the controller needs to negotiate Type 2 PD over the data link layer. As I understood it the "controller" here is the microprocessor, not the PoE module. The PoE module doesn't touch the data layer, right, since that goes on separate wires to the phy. Anyway, it's also very possible that I'm misunderstanding the basic terminology here...

jordens, 2019-09-11:
Ah. That's LLDP over Ethernet for data layer classification (DLC) as opposed to physical layer classification only which we are doing. I am a bit unsure about the standard and when DLC for type 2 is a must. The datasheet calls it a "should".
The switches I have (but no Cisco) don't need DLC.

hartytp, 2019-09-11:
Okay, well may or may not be an issue for the switches people want to use. But worth bearing in mind.

jordens, 2019-09-11:
Yes. If this turns out to be a problem or desirable feature, then implementing LLDP DLC doesn't look to complicated.

hartytp, 2019-09-18:
Taking prelim data (will post in morning) but RMS noise is about 2LSB with PoE, not bad!

Assume thermistor is `dR/dT = 4.4e-2/K`. Thermistor voltage is approx `V_th=Vr/2`, `1LSB = Vr/2^24 = Vth/2^23=5nK`

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

hartytp, 2019-09-18:
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

rms noise is about 15nK, pk to pk is 0.1uK

hartytp, 2019-09-18:
Nice! Impressive it works so well with PoE!

jordens, 2019-09-19:
That's really good.
What's the limit here? If I am not wrong, this meets the datasheet (16 S/s with the 50 Hz filters: ~0.5µVrms ~2LSBrms).

hartytp, 2019-09-19:
Yes @jordens my understanding is that this measurement is roughly consistent with the noise floor of the ADC with the filters we've chosen and the buffers enabled. Not going to gaurantee that's still going to be with case with the TEC drivers at full whack however.

What's interesting is that upping the sample rate doesn't really affect the noise floor, only the 50Hz rejection. even then, in most cases the noise floor could be quite a bit higher without issue, so there is room for users to trade off sample rate v noise rejection if they desire...

jordens, 2019-09-19:
Exactly. 16 S/s and a couple Hz loop bandwidth would be slow for small and tightly coupled thermal loads. And 0.1µK would be too good.  ;)

pathfinder49, 2019-09-19:
I've logged the ADC reading for a longer duration. The measurement was done in an office environment with a lot of electronics running in the surrounding and no temperature stabilization.

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#

The room was vacated from about 6000 s to 11500 s. During this period the ambient temperature was significantly increased due to poor ventilation. I'd estimate the temperature increased by over 5 K.

All in all this looks promising.

jordens, 2019-09-19:
What's `np.diff(data).std()/2**.5` for that (cheap trick for suppressing the low-f instability of normally distributed noise)?

pathfinder49, 2019-09-19:
> What's `np.diff(data).std()/2**.5` for that (cheap trick for suppressing the low-f instability of normally distributed noise)?

in units of LSB 2.51

gkasprow, 2019-09-19:
Would on-board temperature sensor make sense to compensate for  ADC temperature coefficient?

pathfinder49, 2019-09-19:
Here is a 10 minute run using the power jack and with the programmer disconnected.

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

This gives np.diff(data).std()/2**.5 = 2.55

pathfinder49, 2019-09-19:
The same as before, but using a 3 m twisted pair to connect to the 10k reference resistor.

Powered via jack and programmer disconnected. (np.diff(data).std()/2**.5 = 2.57)

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

Powered via PoE and programmer connected. (np.diff(data).std()/2**.5 = 2.53)
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

hartytp, 2019-09-20:
> Would the on-board temperature sensor make sense to compensate for ADC temperature coefficient?

hartytp, 2019-09-20:
> Would the on-board temperature sensor make sense to compensate for ADC temperature coefficient?

The ADC has a temperature sensor inside it that can be read out (at the expense of a 30% reduction in data rate). It would then be trivial to compensate the temperature coefficient in software, although it would probably have to individually measured for each board.

Based on the expected temperature coefficient for the circuit, and from the data posted above, my expectation is that the temp co will be low enough that users won't want to bother compensating it.

The caveat will be that if the TEC drivers make the board temperature vary strongly with the TEC current due to poor thermal management, then this might become an issue. But, hopefully with decent thermal management we can make this a non-issue.

hartytp, 2019-09-20:
> Exactly. 16 S/s and a couple Hz loop bandwidth would be slow for small and tightly coupled thermal loads. And 0.1µK would be too good. ;)

Indeed. Obviously, if we want an easy factor of 2 in bw, we could switch to using 2 single ADCs instead of a dual. IME it's not worth it, since the control loops one wants are generally quite slow, but I'm happy to be corrected if that's not true for other people's use cases.

hartytp, 2019-09-20:
> The same as before, but using a 3 m twisted pair to connect to the 10k reference resistor.

NB this cable was completely unscreened.
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
hartytp, 2019-11-12:
Awesome, so no short-term glitches evident at all when we step the TEC current -- just slow thermal effects. Very good!

pathfinder49, 2019-11-12:
A quick attempt at getting noise characteristics at different TEC drive powers. The settling time is quite long, I'll follow up with a longer settling time.

Setup:
- using PoE
- TECs driving 1 Ohm resistors
- ADCs connected to 10 kOhm reference resistors
- ch1 has modified grounding

TEC settings (ch 0 & 1 are both kept at the same current)
initially: 0 A
600 - 1200 s: 0.5 A (each)
1200 - 1800 s: 1 A (each)
then 0A
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
 (each)

hartytp, 2019-11-12:
Nice. So, am I right in saying that:
- with the star ground/kelvin connection we no longer see any glitches/offset changes on the ADC due to the TEC current (although there are slower thermal effects)
- to within a a factor of two, the RMS noise doesn't change depending on whether PoE/barrel connector is used and what the TEC current is? With the post filter on, it's always a few LSB RMS

If so, I think we're done with noise measurements. Just need to look at the temp co and board temperature and we're finished.

pathfinder49, 2019-11-12:
For both channels driving a 2.6 A current: (The board was disturbed several times during the measurement period)

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

pathfinder49, 2019-11-12:
Now with the TEC enabled, but set to drive 0 A:

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

hartytp, 2019-11-12:
Cool. So the noise is basically the same with PoE and barrel connector and doesn’t change with the tec current?

pathfinder49, 2019-11-12:
> Cool. So the noise is basically the same with PoE and barrel connector and doesn’t change with the tec current?

The noise is TEC current dependant for 2 A tge noise is about 2x that of 0.6 A

hartytp, 2019-11-12:
Really? here it looks like the noise is constant across changing TEC currents... https://github.com/sinara-hw/Thermostat/issues/46#issuecomment-552671356

pathfinder49, 2019-11-13:
> Really? here it looks like the noise is constant across changing TEC currents... [#46 (comment)](https://github.com/sinara-hw/Thermostat/issues/46#issuecomment-552671356)

It's the only difference between my two most recent measurements.

pathfinder49, 2019-11-13:
I've had a quick look at the noise TEC relation and it seems like it might be thermal.

I've measured stepping the TEC current from 0 A -> 1 A (@600 s) -> 2 A (@1200 s) -> 0 A (@1800 s)
As the noise seemed structured I covered the ADC with paper for the second data-set below. This appears to reduce noise when driving large TEC currents.

The board was powered from PoE

ADC data

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

Floating standard deviation
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

ADC covered by paper

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

hartytp, 2019-11-14:
Thanks!

So, the conclusion is that with the fixed grounding we see no "glitches", short-term ADC offset changes or changes in the RMS noise as a function of TEC current, either with the barrel connector or the PoE. That's very good.

There is maybe a bit of extra noise on a ~seconds timescale at higher TEC current, which looks likely to be thermal. But, it's only an extra 10uK RMS or so, so pretty negligible.

Overall, that looks very good.

Can you post a temp co measurement please? Then we're done.

pathfinder49, 2019-11-14:
Here are yesterdays temp co measurements.

Configuration as follows:
- 10k reference resistors directly connected to ch0&1
- TEC driver enabled, but set to not drive current (+ no load connected)
- Power from PoE
- Board placed on a hot-plate, covered by paper towel and a box
  - The resistors were left outside the box to achieve a more stable temperature.
  - Temperature was allowed to settle for ~20 minutes before measurements

Noise was consistent between the two measurements. The measured voltage changed by about 1000 LSB.

Hot plate set to 30°C
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

Hot plate set to 70°C
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

hartytp, 2019-11-14:
Thanks @pathfinder49 Okay, I'm happy that this design is now really well tested and works beautifully. Thanks all

hartytp, 2019-11-14:
So, that's something like 25LSB/K temp co.

A standard thermistor is approx 5e-2/K. So the 5ppm/K resistors we have on the board are 1e-4 less sensitive. If we assume the temp co is dominated by a single 5ppm/K resistor then we'd expect 1e-4K/K. That's a 20LSB/K temp co. In other words, that measurement looks roughly consistent with a naive estimate of the temp co for the design (assuming the ADC contributes negligibly).

Great!

NB with the board running at max temp lying flat on a desk, the ADC got to ~60C (TEC driver at 120C) in 25C ambient. That's 35C change in temp so we'd expect a total change in temperature measurement of 3.5mK.

Closed 2019-11-14.

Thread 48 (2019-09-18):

3V3A current draw

hartytp, 2019-09-18:
Input voltage on R35 is 5V0 as expected, output voltage is 2.938V suggest current draw is 62mA, which is more than an order of magnitude more than expected...

hartytp, 2019-09-18:
This is the junction between R39 and R40 (i.e. the high side of the thermistor input)
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

Voltage change is approx 100mVpk-pk so current is about 20uA pk-pk. So, this appears to be the sampling current. ADC ref buffers should be enabled. That's out of spec
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

hartytp, 2019-09-18:
@gkasprow why is there a 3V3 Zener on the 3V3 rail?

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

hartytp, 2019-09-18:
Yes, removing that diode fixes this

hartytp, 2019-09-18:
But, we still see 100mV on each ADC input

hartytp, 2019-09-18:
The sampling issues were a bug in the firmware (setup register bits not correct, so input buffers weren't enabled)

cc @astro

gkasprow, 2019-09-18:
The diode was used just in case when somebody connects, let's say 12V to the sensor input. In such a case, R40/R42/R46/R48 would be damaged, not ADC. We should replace it with 3.6V one.

gkasprow, 2019-09-18:
There are 10nF capacitors at the ADC inputs, so it cannot be caused by sampling current

hartytp, 2019-09-18:
> The diode was used just in case when somebody connects, let's say 12V to the sensor input. In such a case, R40/R42/R46/R48 would be damaged, not ADC. We should replace it with 3.6V one.

Sounds good! Just something that doesn't conduct more than a few mA at 3V3!

> There are 10nF capacitors at the ADC inputs, so it cannot be caused by sampling current

Look at the time scales involved. It's a DC change in the input level that occurs when the inputs are connected to the internal mux. The specification I posted above is 6uA/V (differential inputs) which gives 20uA for a few V differential. So, this is within spec. Just a fw bug that meant that the buffers weren't correctly enabled.

gkasprow, 2019-10-26:
D12 replaced with 1SMA5914BT3G

hartytp, 2020-09-10:
@gkasprow 1SMA5914BT3G is a 3.42V min diode, which still seems a bit low. Can you remind me what the intention of D12 is? Is it to protect the ADC? If so, why not use a 5V Zener (see the ADC abs max ratings below)?

In the current hardware, Vref is still ~3.1V which is a bit low (not low enough to cause major issues I think, but lower than we would like).

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

gkasprow, 2020-09-10:
Yes, it was to protect the ADC in case of shorting the inputs to 5V

hartytp, 2020-09-10:
> Yes, it was to protect the ADC in case of shorting the inputs to 5V

You mean if the ADC inputs accidentally get shorted to the TEC driver?

Unless I'm mis-reading the ADC abs max ratings, this wouldn't be destructive to the ADC. But, maybe you're worried about the higher IO voltage damaging the microprocessor?

gkasprow, 2020-09-10:
It would be destructive to 51OHm resistors because ADC inputs are bypassed by protection diodes. DAC has a dedicated LDO.

gkasprow, 2020-09-10:
U can measure the voltage drop on R35 and see if it is still an issue. We can use a slightly higher voltage diode, but note that if one shorts input to let's say 12V, a lot of current will flow through it and may exceed 6.5V on ADC

hartytp, 2020-09-10:
> It would be destructive to 51OHm resistors because ADC inputs are bypassed by protection diodes. DAC has a dedicated LDO.

I don't follow you...The Zener doesn't help to protect the 51 Ohm resistors at present...

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

> We can use a slightly higher voltage diode, but note that if one shorts input to let's say 12V, a lot of current will flow through it and may exceed 6.5V on ADC

We should be clear about our goals here...

There are lots of places in Sinara where it's easy to cause damage. e.g. connecting a clock input to a 5V TTL will generally do the trick. I don't think it's reasonably possible to protect against that kind of thing so we have to assume a certain level of competence from users.

Protecting the ADC inputs from 5V seems like a good idea to me because mis-wiring that connector and accidentally connecting an ADC input to the TEC driver is a relatively easy mistake to make (not that easy given the pin locations but I can see it happening). So, if we can make the system robust to 5V being applied to the ADC then let's do it.

However, I do not see any obvious mechanism for 12V getting onto the ADC inputs, so I don't think we should even try to protect against that (and, to do so we'd have to add current limiting resistors in the input path so we'd need to think about noise, offsets etc before doing that)....

hartytp, 2020-09-10:
@gkasprow without the Zener didoe, what happens if a user applies 5V to the sensor input? As far as I can tell, the ESD diodes will cause the ADC 3V3 rail to increase to close to 5V. That will not be destructive to the ADC.

However, it will lead to the ADC digital output logic level going to 5V. Since the microprocessor is powered from 3V3 I assume that will be destructive (but correct me if I'm wrong) or do you think the resistors currently in place will be sufficient for current limiting.

My guess is that it will be hard to find a Zener with a low enough leakage current at 3V3 to avoid causing annoying sag in that supply rail, but still low enough voltage to keep the microprocessor within spec for 5V applied to the ADC input. Maybe a better path forwards is to make sure we have current limiting resistors to protect the microprocessor?

gkasprow, 2020-09-10:
4v diode (1SMA5916BT3G) would do the job

hartytp, 2020-09-10:
works for me...

hartytp, 2020-09-11:
@astro measured 1.75V across R35, meaning the LDO input voltage is only 3.25V. The LDO output is ~3.0V. Let's go to a 4V diode.

gkasprow, 2020-09-11:
And with the diode removed, the drop is much lower?

hartytp, 2020-09-11:
That was my observation in the previous hardware revision (which was the same other than the diode)...

gkasprow, 2020-09-15:
Now the voltage drop on R37 is 38mV with TVS installed and the same value with TVS removed, so correct TVS model seem to work fine

hartytp, 2020-09-15:
> Now the voltage drop on R37 is 38mV with TVS installed and the same value with TVS removed, so the current TVS model seem to work fine

? Did you measure that on hardware?

@astro reported 1.75V across R35...

gkasprow, 2020-09-15:
Yes, but I measured it on v2.0 HW. It has a 1SMA5914BT3G diode (814B marking)

gkasprow, 2020-09-15:
in my case it is 1.66V on R35 with diode assembled

hartytp, 2020-09-15:
> Now the voltage drop on R37 is 38mV with TVS installed and the same value with TVS removed, so the current TVS model seem to work fine

R37 is not relevant for this.

> in my case it is 1.66V on R35 with diode assembled

That's about consistent with @Astro's findings and suggests that the diode is a problem here.

gkasprow, 2020-09-15:
..and 60mV with diode removed. Sorry, I was measuring on the wrong resistor. Diode current does not pass via R37

hartytp, 2020-09-15:
okay, thanks for confirming. Let's verify with the other diode you suggested and check that the voltage drop is acceptable.

gkasprow, 2020-09-15:
I will order 1SMA5916BT3G and 1SMA5915BT3G and see which one works.

gkasprow, 2020-10-11:
with 1SMA5915BT3G i measure 0.76V,
with 1SMA5916BT3G the drop is 250mV

hartytp, 2020-10-11:
@gkasprow the 1SMA5916BT3G  looks like it should be sufficient to prevent damage to the microprocessor. What do you think?

gkasprow, 2020-10-11:
I think so.

gkasprow, 2020-10-13:
fixed

Closed 2020-10-13.

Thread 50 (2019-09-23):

Dead 3V3 SMPS

hartytp, 2019-09-23:
@gkasprow out Thermostat card started playing up and the ADC suddenly became quite noisy. We noticed that the 3V3 LDO for the ADC was at 4V. It seems that the microprocessor digital outputs had hit 4.6V or so and were powering the LDO through the protection diodes.

After a bit more digging, it seems that the main 3V3 SMPS is now running at close to 5V.

I can't see any obvious way this could have happened. The main thing we've done to the board is to plug and unplug the PoE quite a few times during testing. I don't expect that to cause an issue, but could be related to https://github.com/sinara-hw/Stabilizer/issues/47 It's also conceivable that some clumsy probing at our end caused damage (although I do not believe that to be the case).

Okay if we send the board back to you for investigation?

gkasprow, 2019-09-23:
Yes please. Its better to figure it out before we go to new revision

Wyslano z Samsung w Plus
Pobierz aplikacje Outlook dla systemu Android<https://aka.ms/ghei36>

________________________________
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

gkasprow, 2019-09-25:
The DC/DC converter is shorted. The only explanation I see right now is transient on 5V rail which caused upper buck converter MOSFET damage.

hartytp, 2019-09-25:
Yes I wondered if that was the problem. Might also explain dead phy on stabilizer.

gkasprow, 2019-09-25:
Stabilizer generates 3V3 in a different way, using another type, single-stage converter which works up to 18V. On the Thermostat, the 3V3 rail is generated from 5V rail with converter that is able to survive max 6V.

hartytp, 2019-09-25:
Okay. Can you have a look at the 5V rail for transients when using PoE please?

hartytp, 2019-09-25:
I don’t have any more boards to test :(

hartytp, 2019-09-25:
Should we consider using the same smps as stabilizer next time to improve robustness?

gkasprow, 2019-09-25:
I was looking at it but did not detect any.
Is it possible that during plugging the PoE or 12V, somebody was touching the bottom side of PCB, under the DC Jack? There is a feedback divider so when sb toches it, may change division ratio and increase the 5V rail...
In case of the Stabilizer, it's much more difficult to access and touch the divider by chance

hartytp, 2019-09-27:
> Is it possible that during plugging the PoE or 12V, somebody was touching the bottom side of PCB, under the DC Jack? There is a feedback divider so when sb toches it, may change division ratio and increase the 5V rail...

I don't believe so, but it's always possible. Can we move these components to somewhere less accessible for the new revision?

Other than that, if you can't see any other issues with the design, let's close for now and reopen if this happens on another board.

Can you send us the repaired board back please so we can finish testing?

Thanks again for the work on this project @gkasprow !

gkasprow, 2019-10-26:
I moved the components to the top layer.

hartytp, 2019-10-26:
Okay. I have no other ideas for what could have caused this so let’s close for now

Closed 2019-10-26.

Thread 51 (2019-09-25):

PoE turns off and on

hartytp, 2019-09-25:
@gkasprow we saw this on one of our thermostat boards. I'll ship it to you for investigation.

hartytp, 2019-09-25:
It did stabilize and stay on eventually, but took quite a while for the switch to stop registering PoE faults

gkasprow, 2019-09-30:
in my lab it works fine
Here is the plot. Blue - 12V
green - PoE voltage before DC/DC
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

gkasprow, 2019-09-30:
The PoE voltage was measured with diff HV x100 probe

hartytp, 2019-09-30:
There is clearly something marginal somewhere so it's only particular combinations of boards and switches that fail to work.

Shall I send you the switch as well?

hartytp, 2019-09-30:
Actually, maybe first try it with the switch that @sbourdeauducq sent you? (Or see if you can reproduce this using the same stabilizer and swtich combination that he had?)

gkasprow, 2019-09-30:
I still didn't get the package from @sbourdeauducq

hartytp, 2019-09-30:
Okay, no problem. I'll send you the switch we used to reproduce this issue with. It's in use now, so will be a few days before I ship it.

gkasprow, 2019-09-30:
Anyway, I go to ESTEC for space & quantum conference, will be back on Friday.

hartytp, 2019-09-30:
Aah, ok. In that case, can you send me the Thermostat back and I'll do the tests.

Which tests would you like to see to debug this issue?

gkasprow, 2019-09-30:
I have with me only one with broken CPU and DC/DC which will pass to Technosytem for reparation tomorrow.

hartytp, 2019-09-30:
And broken ADC (the CPU applied 5V to the ADC via the digital outputs). So, most of the PCB is dead :(

I think you have two I sent you...one with the broken 3V3 SMPS (but working PoE) and one with a working SMPS but dodgy PoE.

gkasprow, 2019-09-30:
yes, but one is at the WUT and I'm leaving tomorrow.

hartytp, 2019-09-30:
Okay, well I need that one to test PoE as the other one doesn't display this issue. No worries if you can't ship it, we can wait until you get back.

hartytp, 2019-10-05:
Can you ship this back to me so I can debug?

gkasprow, 2019-10-05:
Yes, I will pass it to TS on Monday.

Closed 2019-10-26.

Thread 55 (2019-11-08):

Significant Coil Whine

pathfinder49, 2019-11-08:
Driving one TEC channel at maximum produces loud coil whine from the area of L2_1, L4_1, L2_2, L4_2. Might be worth checking everything is within spec.

Driving both TEC channels at maximum produces a louder whine followed by a shutoff after a few seconds.

This was observed when powering the board from the 12 V jack.

hartytp, 2019-11-08:
> Driving both TEC channels at maximum produces a louder whine followed by a shutoff after a few seconds.

I suspect the shut-off is a separate issue to the whine.

If the whine depends on the total power then it's possible it's the 5V SMPS rather than the TEC driver coils...

pathfinder49, 2019-11-08:
The inductors are also getting hot to the touch. L4_x seem to also be getting hotter than L2_x.

gkasprow, 2019-11-08:
you can observe the 5V rail to see if there are oscillations.
Shut off can be caused by thermal protection of the buck converter.

hartytp, 2019-11-09:
aside from the whine, the TEC driver inductors get scorchingly hot.

To do: review this part of the design and see if we want to make any changes. FWIW those inductors look pretty nice and seem to have an appropriate current rating so there may not be much we can do.

hartytp, 2019-11-18:
@gkasprow please can you review all coils/CMCs used in this design and check you're happy with them. 3A doesn't seem like such a high current to me, so I'm surprised the whine is this bad. Still, once Thermostat is in a box no one will notice, so if you're happy with the current parts feel free to close

gkasprow, 2019-11-21:
if it is audible, it means that there is some low-frequency component that is modulating the Peltier current.
Ceramic capacitors can also produce sound, especially ones with X7R  dielectric.
I'd measure the LF AC component of the TEC voltage to figure out the frequency range.

hartytp, 2019-11-21:
Okay, I'll try to find time to stick a scope on the TEC voltage tomorrow. @pathfinder49 is everything still set up for me to do this quickly?

pathfinder49, 2019-11-21:
I've disassembled things, but everything should still be in the same place.

hartytp, 2019-11-22:
@gkasprow we had another look at this issue. It appears that when the TEC driver gets close to saturating it starts cycle skipping. In our tests, one of the FETs was on almost constantly, and was only turning off briefly every ~400us. So, the switching frequency was much lower than designed.

Not sure if the low impedance of the inductors at this frequency was causing large current spikes to flow through the capacitors, or if the lower frequency just made the dynamics audible. Either way, turning the set current down a little so that the driver stopped cycle skipping the noise appeared to go away immediately.

As for which components were actually whining, it's hard to say. We tried the old "straw in the ear" technique to localize the whine, but it's hard to pin down precisely. I thought that the loudest whine was around the 5V SMPS. I think it was the ceramic capacitors at the SMPS output, but it could also have been the inductor inside the SMPS. Hard to say. There may also have been some capacitor/coil whine at the TEC driver output, but it's hard to say.

hartytp, 2019-11-22:
@gkasprow I don't think there is anything concerning here, so I'm closing.

If you're worried about the inductors/capacitors whining when the TEC driver gets close to saturation then please reopen.

jordens, 2019-11-22:
If it also does cycle skipping near the current zero crossing, that would be problematic as would make it electrically noisy for small thermal loads (i.e. laser diode off and near room temperature).

hartytp, 2019-11-22:
It doesn’t do this at 0 current. It behaves nicely as described in the data sheet (both FETs run at 50% duty cycle to give 0V differential across the load). This is purely an issue at saturation afaict

jordens, 2019-11-22:
I see. Nice.

Closed 2019-11-22.

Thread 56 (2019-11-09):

Change in ADC offset with TEC current

hartytp, 2019-11-09:
Data from here: https://github.com/sinara-hw/Thermostat/issues/46#issuecomment-551932456

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

@pathfinder49, do you have the raw data for that?

@pathfinder49 do you agree with the following statements based on the data you gathered?
1. Regardless of which TEC the current is applied to, the offset change is bigger for channel 1 than channel 2
2. (1) strongly suggests that the issue isn't related to the reference voltage or a supply rail, since that would presumably be common-mode to both channels
3. For driving channel 0, the effect is larger when the TEC is positive than when it's negative.
4. One interpretation of (1) and (3) would be that the effect is larger when the current flows through L2, and largest when it flows through L2_1. This could well be an indication that pick-up on the ADC lines (which run along the bottom-edge of the topside of the PCB) is the issue (L2_1 is right next to those lines).
5. There is also a slow baseline drift in the measurement which is presumably just the board heating up. We will measure the temp co, but I'm not too surprised to see sub-mk changes in the measured reading when the board starts to get that hot. I suspect that even some mild forced air cooling would make this a non-issue...
6. The change in ADC offset with TEC current is not linear.

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

hartytp, 2019-11-09:
(previous comment updated)...

hartytp, 2019-11-09:
Here is my theory: it's the ESD diodes we added very slightly rectifying the pickup. NB there isn't an EMI filter before the diodes, so any RF pickup reaches them unfiltered.

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

@pathfinder49 can you quickly test this next week by trying something like:
- Add some large ceramic capacitors (100nF or even 1uF) here...

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

Or just remove D17 D18 D19 and D20

hartytp, 2019-11-09:
If that fixes the problem then the suggestions for the new revision are:
1. Be more careful with thermistor input trace routing (we now have 4 layers so can do this via internal screened layers)
2. Put an EMI filter before the diodes

pathfinder49, 2019-11-10:
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

I'd mostly agree...

1. ch1 has a bigger response than ch0 to TEC0. However the TEC1 response is similar.
6. I will plot this tomorrow. However some quick calculations indicate the response is linear.

pathfinder49, 2019-11-10:
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

I'll have a go at that.

pathfinder49, 2019-11-11:
The ADC offsets appear consistent with a response proportional to TEC current. However, the gradient appears to be different for different sign currents and for different TEC/ADC channels,
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

pathfinder49, 2019-11-11:
On a second look, the TEC1 response is not linear. (editing plot above to include starting position)

hartytp, 2019-11-11:
Ok. Well, either way, let's figure out the cause.

I see two possibilities: ground loops or diode rectification.

We can quickly check rectification by adding capacitors on the diode inputs (see above).

To check for ground loops, we can rotate the input resistors to ground by 90deg (or lift them from the pads) and add a wire to the ADC ref- pin. That way we have a Kelvin connection so aren't sensitive to ground currents.

I bet one of those two will kill this issue...

Closed 2019-11-18.

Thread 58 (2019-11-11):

kelvin-connect the TEC divider to ground near the reference

hartytp, 2019-11-11:
to minimize sensitivity to ground loops...

hartytp, 2019-11-12:
Let's also use star-routing on the Vref+ TEC lines to avoid cross-talk between the two TEC lines. Basically, have stars on both TEC+ and TEC- that go to the ADC REF+ and REF- lines.

gkasprow, 2019-11-20:
do you mean this ground?
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

gkasprow, 2019-11-20:
TEC+ and TEC- are routed to the diff amplifiers. And the divider ground should indeed be connected as close to CPU as possible.

gkasprow, 2019-11-21:
OK, so I implemented star connection for both ref and divider GND
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

hartytp, 2019-11-21:
@gkasprow sorry! I meant that we should kelvin-connect the thermistor v_ref+ and v_ref- to near the ADC. Not the TEC driver.

hartytp, 2019-11-21:
i.e. what I want to do here is (a) fix the ground loop that caused the ADC offset to vary with the TEC current (b) minimize the coupling between the two ADC channels.

gkasprow, 2019-11-21:
In such case, one has to make sure that return current does not pass via sensitive analog circuits.
It should be enough to add a plane cutout that will make the current loop much smaller.

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

I also added Kelvin connections for thermistors. I used net ties to make sure the vref- won't be shorted to GND by coincidence.

gkasprow, 2019-11-21:
Vref+
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
Vref-
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

Closed 2019-11-21.

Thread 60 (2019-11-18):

extra EMI capacitors

hartytp, 2019-11-18:
To avoid any rectification by the EMI diodes, let's add extra EMI capacitors like this:

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

gkasprow, 2019-11-20:
shouldn't they be added to GND? Otherwise large CM signal can still be rectified.

hartytp, 2019-11-20:
Yep you’re right. Add a larger dm cap as well to avoid cm to dm conversion (or copy the caps from the rfi filter to make it two stage)

gkasprow, 2019-11-20:
Can we stick with such design?
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

Closed 2019-11-21.

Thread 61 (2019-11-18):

ref 2V5

hartytp, 2019-11-18:
This currently looks to be driven by both the 24-bit ADC and the MCP1525T.

AFAICT it would be better to power the microprocessor ref from a 3V3 reference anyway: currently we have separate dividers for the DAC output going to the TEC driver/microprocessor. That will limit the accuracy of the TEC driver calibration. If we used a 3V3 microprocessor reference then we could scrap the divider for the microprocessor...

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

hartytp, 2019-11-18:
Changing the microprocessor reference will also require changing the resistors used for the TEC current measurement.
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

gkasprow, 2019-11-20:
The assembly variant makes the MCP1525 DNP so the CPU ADC is driven from the 24bit ADC.
We don't have any 3V3 reference. I would have to replace the MCP1525 with a 3V reference. I'm not sure if we gain a lot here. We will add yet another reference voltage that is not related to ADC reference nor DAC reference.

hartytp, 2019-11-21:
I'd like to be able to have the same divider on the DAC outputs going to the microprocessor and TEC driver so we don't need to think about tolerances on the dividers.

I'd be happy with:
- generate a 3V0 (or 3V3) microprocessor reference by dividing the 5V0A rail with a resistive divider (IIRC the microprocessor has a ref buffer so this can be relatively high-Z)
- use a filtered version of the 3V3 SMPS rail for the microprocessor ADC reference.

hartytp, 2019-11-22:
@gkasprow do you think we can get v2.0 ready to ship on Monday?

hartytp, 2019-11-25:
ping @gkasprow when can we get this sent off?

gkasprow, 2019-11-29:
I didn't look here for a while. Next time just write an email. All github issues mails land in dedicated folder. Yes, we can produce it on Monday.

hartytp, 2019-11-29:
Great. Can you produce an RC before that so I can sign off on the final changes?

gkasprow, 2019-11-29:
the reference input in STM32F4 is not buffered
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

the easiest is to add opamp buffer (LMV321ILT) that we already use and remove MCP1525 to make space

gkasprow, 2019-11-29:
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

gkasprow, 2019-11-29:
the DAC output would look like this.
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

The 1k6 at the output isolate DAC from ADC current pulses caused by ADC sampling circuit

hartytp, 2019-11-29:
Lgtm

Closed 2019-11-29.

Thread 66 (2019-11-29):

Thermal sheets

hartytp, 2019-11-29:
Try them with v 2.1 to see if we can conduct heat from the tec drivers to the enclosure

gkasprow, 2019-11-30:
@hartytp how many v2 boards shall we produce?

hartytp, 2020-02-28:
@gkasprow Thermostat v2.0 has arrived from TechnoSystem. The enclosures look great! Can't wait to try it.

Currently it doesn't have the thermal sheeting we previously discussed (to improve the heat conduction from the PCB to the case).

Can you recommend a PN for the thermal sheeting we should use and give some advice on how to install it/what we're trying to achieve (i.e. is the idea to just uniformly coat the PCB and also get a thin layer that will squish in the slot where the PCB mounts to the case to improve conductivity?).

Once the new FW is ready, we'll test the thermal performance both with and without the sheeting and see if it's worth it. If it is, the we should add it to the BOM.

gkasprow, 2020-02-28:
I didn't see them. I'll ask TS for additional unit I could test. I have such sheets in my lab.
I'd try to use one of[ these](https://pl.farnell.com/w/c/zarzadzanie-chlodzeniem-i-temperatura/materialy-przenoszace-cieplo/materialy-termoprzewodzace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|2mm|2.032mm|2.54mm|3mm|3.175mm|3.18mm|3.2mm|4mm|4.1mm|5mm|5.08mm&range=inc-in-stock), just choose one with right thickness. Glue Alu foil on top to make the PCB  insertion feasible.

hartytp, 2020-02-28:
Aah cool! Ok you have a play with it and tell us what you think we should do.

hartytp, 2020-02-28:
Let me know if you need me to send you a Thermostat

gkasprow, 2020-02-28:
I have one thermostat, just need an enclosure with panels. I will get them from TS on Monday. From you, I need a firmware that is able to provide the conditions I need. I can also attach tiny PT1000 to measure temperatures.

hartytp, 2020-02-28:
Right now there isn’t any firmware for the v2 hardware (STM micro). M-Labs are planning to port their firmware. We can put this testing off until the new firmware is ready if it’s easier, there isn’t a rush on this...

gkasprow, 2020-02-28:
OK, I can generate some simple code with CubeMX and make PWMs running to dissipate some power.
However if Mlabs firmware is coming soon, it's better to wait.

sbourdeauducq, 2020-03-24:
The board gets surprisingly hot, with only 1 TEC connected.

hartytp, 2020-03-24:
I assume it's comparable to the v1.0 hardware that we characterized before (several sets of ~85% efficient SMPSs add up to quite a bit of power dissipation)? See the thermal images we posted.

Once the firmware works well enough it would be great for @gkasprow to have a play with thermal conductive sheets as discussed above.

gkasprow, 2020-03-24:
In a few days I will receive the multi-point thermometer so will do detailed analysis with thermal sheets and without them.

hartytp, 2020-03-24:
Great!

gkasprow, 2020-10-11:
I wrote a half a year ago about the multi-point thermometer. I received two such boxes a few days ago ...
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

gkasprow, 2020-10-31:
@hartytp look [here ](https://github.com/sinara-hw/Thermostat/issues/73#issuecomment-719834216)

Closed 2020-11-02.

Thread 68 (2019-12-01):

star ground

hartytp, 2019-12-01:
@gkasprow I don't have altium, so it's hard to follow the layout. But, just to check: the thermistor ref gnd should be tied to ADC pin 2 (ref -) but on the schematic it looks like it's tied to C54. Why is this?

hartytp, 2019-12-01:
@gkasprow can you sketch out the routing of the ref and ref GND to the thermistors for me please?

hartytp, 2019-12-01:
FWIW I don't understand why IC14 uses the ADC 2V5 reference and REF GND. Why not just use the TEC ref output? Would simplify the routing and ensure that we don't accidentally couple noise form the TEC to the ADC.

Not a big deal and probably not worth changing now, I just don't understand why it was done -- although, I suspect it was a mis-communication between us.

hartytp, 2019-12-01:
@gkasprow thanks again for all the work on this.

It's hard to follow the layout from the PDFs, but the bits I can follow look really nice. Good work. Will be very curious to see what happens when we stabilise one of our cavities. <100uK RMS?

gkasprow, 2019-12-01:
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

gkasprow, 2019-12-01:
I used net ties to make sure the GND is not shorted to GND. Net tie creates a different net names while providing physical connection. ADC ref- goes to GND so it is the same net. I can change on the schematic but it does not change anything on PCB.

hartytp, 2019-12-01:
Okay that’s pretty good

I would prefer if possible to have the star ground for the ref - right at the ADC ref - pin rather than at the ep. But that’s close

gkasprow, 2019-12-01:
OK, no problem. It that make you sleep better... :)

hartytp, 2019-12-01:
Your call. Either route as a proper star ground right to the pin or close now if you think it’s not worth it (in any case the new layout with gp cuts and more layers should make these ground issues less of a provlem)

hartytp, 2019-12-01:
Thanks! The thing killing my sleep right now is booster

gkasprow, 2019-12-01:
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

hartytp, 2019-12-01:
Perfect

gkasprow, 2019-12-01:
True, IC should use ADC reference. 2V5 does not much sense here. It is residue from previous revision.

gkasprow, 2019-12-01:
I mean IC14 and CPU ADC

hartytp, 2019-12-01:
Indeed. I think that right now the only thing that uses the ADC ref is that opamp and that should probably use the tec ref for convenient (the tec voltage measurement doesn’t need to be particularly high accuracy).

hartytp, 2019-12-01:
If you can be bothered then fix it as it makes the design neater, but it’s not crutical

gkasprow, 2019-12-01:
fixed

Closed 2019-12-01.

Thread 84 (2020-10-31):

Thermostat v2.2 changes

gkasprow, 2020-10-31:
The new release will have the following changes:
- [x] replace TEC inductors with ones having lower losses
- [x] add fan
- [x] add fan fixing holes to the enclosure
- [x] add PWM support for the fan
- [x] add PHY protection resistors and better-suited TVS
- [x] add 10x25x10 heatsink on top of the inductors. It improves the air flow distribution and significantly lowers components temperature.

hartytp, 2020-11-02:
Track any other improvements from the EEM version.
- [ ] improvements to PoE module layout for thermal performance

dtcallcock, 2020-11-21:
On v2.0 the BOOT0 jumper (JP2) is not labelled on the silkscreen.  Not a huge deal but annoying to have to go through the schematic and figure it out.

jbqubit, 2020-12-06:
- [ ] Fix channel-crossed SENS inputs.

jordens, 2020-12-08:
Pleas don't change that as long as it introduces incompatibilities and as long as there are unaddressed impacts on the firmware.

gkasprow, 2020-12-08:
It can be fixed in firmware already

jordens, 2020-12-08:
Exactly.

gkasprow, 2021-03-15:
PoE thermal issues seem to be solved by a fan and a heatsink on top of the inductors which redirect part of the flow to the PoE module. I described it in #93

gkasprow, 2021-03-15:
added heatsinks
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

Closed 2021-03-15.

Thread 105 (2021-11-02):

Component links are not up-to-date

maciejprzybysz, 2021-11-02:
It causes problems with assembly variants.

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

Closed 2021-12-13.

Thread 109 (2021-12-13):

Thermostat 2.2.1 changelog

maciejprzybysz, 2021-12-13:
+ Component links updated #105
+ Problems with Assembly Variants resolved #105
+ Compilation errors resolved #104
+ D21 changed to DRTR5V0U4S-7 #98
+ 1uF: C13, C101, C25, C26, C28 changed to 0603 to reduce BoM #108
+ 1nF: C10 changed to 0402 to reduce BoM #108
+ 10nF C45, C47, C52, C55, C104, C106, C107, C111 changed to 0402 to reduce BoM #108
+ 82k: R14 changed to 0603 to reduce BoM #108
+ 100nF: C27 changed to 0402 to reduce BoM #108
+ R98 changed to 1.6k to reduce BoM #108
+ Test points changed to "No BOM" #108
+ L8 moved .254mm from the board outline #102
+ Ground separation line moved not to cross UART signals #106
+ P3V3 connection to W1/JP2 improved #107
+ Overlay issues resolved #99
+ TLV62565DBVT footprint changed to be compatible with TLV62566/8/9 in SOT23-5 and SOT23-6 #101
+ Schematic sheet templates updated with proper WUT logotype and revision number
+ Revision number on PCB updated
+ J7, J8, J12 3D models moved form Mechanical1 to Mechanical13
+ "Comment" field in BoM filled with P/Ns for: J4, J5, J7, J8 (was empty).
+ Board outline corrected (Outline on Mechanical1 was not closed shape), board dimensions not changed

maciejprzybysz, 2022-02-21:
2.2.1rc2
- R94 Value changed to 200k
- Revision on panel changed to 2.2.1
- Variants modified: IC10 changed to be mounted

Closed 2024-06-17.

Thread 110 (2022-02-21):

#SHDN and FREQ signals need voltage level translator

maciejprzybysz, 2022-02-21:
MAX1968 #SHDN and FREQ pins are driven from STM32 with 3V3 logic levels. MAX1968 Electrical Characteristics specify min. input high level voltage as Vdd x 0,75 and low level voltage as Vdd x 0,25. On Thermostat MAX1968 is powered from 5V, so low level voltage should be max. 1,25V and high lvl voltage min. 3,75V. I think we should add voltage level translator in the next revision.

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

The same issue applies to all previous versions, but despite the difference in voltages, it has worked fine so far. Since release 2.2 additional 10k pulldown resistor R94 has been added to project (#94 ). This pulldown in combination with a 2k series resistor (R31 & R85) on the #SHDN line made a voltage divider and a high level voltage dropped below 3V. As a result, MAX1968 stopped turning on.

In 2.2.1 release we changed R94 resistor to 200k (we produced this version before finding the problem). This helps to prevent TEC driver turning on before system start and still allows the driver to be turned on by STM32. We made tests with 200k and 1M pulldown resistor in temperature range from 20°C to 80°C. Scopes from corner cases attached below.

RED: #SHDN with 1M pulldown
YELLOW: TEC Voltage on channel with 1M pulldown

BLUE: #SHDN with 200k pulldown
GREEN: TEC Voltage on channel with 200k pulldown

Both 1M and 200k pulldowns worked fine in 20°C. During startup max Voltage on #SHDN was 650mV with 1M and ~160mV with 200k, so TEC didn't started.

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

During normal operation at 20°C both resistors worked fine. STM can drive MAX at ~3.3V level.
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

After heating up device to 80°C, 1M pulldown was too weak to prevent turning TEC driver on during power up. (diodes D24/D25 reverse current increased) Voltage on #SHDN increased to ~2.5V.
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

200k pulldown still was strong enough at startup. Voltage on #SHDN was ~900mV, so less than max low voltage level (1,25V) from TEC driver specification.
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

Both 200k and 1M allowed to drive #SHDN from STM32 at ~3.3V level.
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

gkasprow, 2022-02-21:
Good catch. One can also use a silicon diode level shifter.

maciejprzybysz, 2022-02-23:
> (..) But my drivers did not turn on at room temp. I will check.

@SingularitySurfer It won't turn on with 10k resistor pulldown even in room temperature. Please notice that the scopes above are taken after changing R94 resistor to 200k on first channel and 1M on another.

gkasprow, 2022-11-21:
Let's add TTL buffer that translates 3.3V logic level to 5V logic level.
74HCT1G125GW
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

gkasprow, 2022-11-21:
fixed in 2.2.2

jordens, 2022-12-07:
Don't you want such a translator for FREQ as well? The screenshot above doesn't have one.

Closed 2022-11-21.

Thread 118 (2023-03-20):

Add diode to prevent powering Zotino and Rack from PoE

jordens, 2023-03-20:
J1/J3 will happily sink power from PoE
Add a (overridable) ideal diode as on Thermostat_EEM

maciejprzybysz, 2023-06-26:
@jordens Could you please describe what exactly is the problem?
As far as I understand this issue, you want to cut off powering Zotino by PoE thorough J1/J3 connector?
Do we need to disable powering Thermostat from Zotino also?
How do we want to switch P12V on J1/J3 (CPU? jumper?)?

maciejprzybysz, 2023-06-26:
> Same as on Thermostat_EEM.

Thermostat EEM do not have connectors for Zotino with P12V as far as I know. I assume you mean P12V_EEM circuit?

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

This circuit is useless in case of switching on/off EEM power supply for Thermostat_EEM. If P12V0_EEM power is present T9 mosfet will be on, no matter what is Force_EEM_Source state. (this should be an issue, shouldn't be?)

> Maybe even simpler/better add a jumper between the RJ45 and the PoE module to disable PoE when connected zo Zotino (even if the PoE module is mounted). That would also solve the issue.

Maybe you could simply turn PoE off on switch config? This wouldn't require Sinara hardware access to modify settings.

jordens, 2023-06-26:
No. That's the intention. It's a diode with an override.

Placing more demand and restrictions on external components makes things harder to use. It's a bad idea.
This is not some "setting": When you connect Zotino, you already have hardware access!

maciejprzybysz, 2024-06-12:
I'd like to make new revision of Thermostat, but I would like to take a broader view first.

Could someone describe use cases of Thermostat? As I understand there are at least 2 scenarios:
1. Standalone version in aluminum case, powered from PoE or front panel 12DC connector, used with 5 pin  J4/J5 backpanel terminal block connectors.
2. 4HP version fitted into Sinara crate, used with Zotino through 10 pin J1/J3 connectors, powered from ........? Molex 4pin or PoE?

Any other use cases?

Ad. 2:
If we use Thermostat with Zotino, what P12V on J1/J3 is used for? As I understand Zotino should be powered from EEM connector in this case, not from Thermostat. Maybe it could be used to power Thermostat from Zotino?

Bonus question:
What is T1 used for? It is described as "reverse protection", but should It be understand as "reverse polarity protection" (It will not work that way) or to cut off PoE output from P12V when not used (this makes some sense if we really use POE_PWR_SRC signal or if AG5300 could not accept any voltage on output when not used, but description is misleading then)

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

@jordens @gkasprow

maciejprzybysz, 2024-08-08:
For now, due to space restriction on PCB and no precise info about use-cases, I just added two 0R jumpers to cut off P12V on J1&J13 connectors to Zotino. This would separate P12V domains if needed.

Closed 2024-08-08.

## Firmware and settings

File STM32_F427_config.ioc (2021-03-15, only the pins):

Mcu.UserName=STM32F427ZITx
PA0/WKUP.Signal=ADCx_IN0
PA1.Signal=ETH_REF_CLK
PA10.Signal=USB_OTG_FS_ID
PA11.Signal=USB_OTG_FS_DM
PA12.Signal=USB_OTG_FS_DP
PA13.Signal=SYS_JTMS-SWDIO
PA14.Signal=SYS_JTCK-SWCLK
PA15.Signal=SYS_JTDI
PA2.Signal=ETH_MDIO
PA3.Signal=ADCx_IN3
PA4.Signal=ADCx_IN4
PA5.Signal=ADCx_IN5
PA6.Signal=ADCx_IN6
PA7.Signal=ETH_CRS_DV
PA9.Signal=USB_OTG_FS_VBUS
PB0.Signal=ADCx_IN8
PB1.Signal=ADCx_IN9
PB10.Signal=SPI2_SCK
PB11.Signal=ETH_TX_EN
PB12.Signal=SPI2_NSS
PB13.Signal=ETH_TXD1
PB14.Signal=SPI2_MISO
PB15.Signal=SPI2_MOSI
PB3.Signal=SYS_JTDO-SWO
PB4.Signal=SYS_JTRST
PB6.Signal=USART1_TX
PB7.Signal=USART1_RX
PB8.Signal=I2C1_SCL
PB9.Signal=I2C1_SDA
PC0.Signal=ADCx_IN10
PC1.Signal=ETH_MDC
PC10.Signal=SPI3_SCK
PC11.Signal=SPI3_MISO
PC12.Signal=SPI3_MOSI
PC13.Signal=GPIO_Output
PC2.Signal=ADCx_IN12
PC3.Signal=ADCx_IN13
PC4.Signal=ETH_RXD0
PC5.Signal=ETH_RXD1
PC6.Signal=S_TIM3_CH1
PC7.Signal=S_TIM3_CH2
PC8.Signal=S_TIM8_CH3
PC9.Signal=S_TIM8_CH4
PD10.Signal=GPIO_Output
PD11.Signal=GPIO_Output
PD12.Signal=S_TIM4_CH1
PD13.Signal=S_TIM4_CH2
PD14.Signal=S_TIM4_CH3
PD15.Signal=S_TIM4_CH4
PD8.Signal=GPIO_Input
PD9.Signal=GPIO_Output
PE10.Signal=GPIO_Output
PE11.Signal=S_TIM1_CH2
PE12.Signal=GPIO_Output
PE13.Signal=S_TIM1_CH3
PE14.Signal=S_TIM1_CH4
PE15.Signal=GPIO_Output
PE2.Signal=SPI4_SCK
PE4.Signal=SPI4_NSS
PE6.Signal=SPI4_MOSI
PE7.Signal=GPIO_Input
PE8.Signal=GPIO_Output
PE9.Signal=S_TIM1_CH1
PF0.Signal=I2C2_SDA
PF1.Signal=I2C2_SCL
PF11.Signal=GPIO_Output
PF12.Signal=GPIO_Output
PF13.Signal=GPIO_Output
PF14.Signal=GPIO_Input
PF6.Signal=SPI5_NSS
PF7.Signal=SPI5_SCK
PF8.Signal=ADC3_IN6
PF9.Signal=SPI5_MOSI
PG13.Signal=ETH_TXD0

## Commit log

2018-07-15 completed PCB and SCH, ready for review
    [CPU_ETH.SchDoc, Thermostat.PrjPCB, Thermostat.schdoc]
2018-08-18 v1.0 production
    [CPU_ETH.SchDoc, Thermostat.schdoc]
2018-08-22 fixed issues from @jordens
    [CPU_ETH.SchDoc, Thermostat.PrjPCB, Thermostat.schdoc]
2020-01-29 added Panel design
    [Panel_Thermostat_Front.PcbDoc, TEC_driver.SchDoc, Thermostat.PrjPCB]
2020-01-31 added 4HP panel design
    [Panel_Thermostat_4HP.PcbDoc, Thermostat.PrjPCB]
2021-02-04 v2.2 work in progress
    [AFE.SchDoc, CPU_STM32F4.SchDoc, RMII_Ethernet.SchDoc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]
2022-02-21 * v2.2.1rc2
    [CPU_STM32F4.SchDoc, Panel_Thermostat_4HP.PcbDoc, Panel_Thermostat_Front.PcbDoc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]
2024-08-08 v2.2.4rc1 * Added/adjusted RC filters on TEC_U_meas(10k/10nF), Vref (0R/1uF), ITEC (10k/10nF) - similar to Thermostat EEM #120 #117 * MicroUSB connector changed #119 * Added alternative terminal bloc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
    [AFE.SchDoc, CPU_STM32F4.SchDoc, RMII_Ethernet.SchDoc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]
